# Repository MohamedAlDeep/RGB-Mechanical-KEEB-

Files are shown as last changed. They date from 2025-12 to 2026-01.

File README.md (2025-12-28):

# RGB Mechanical 75% KEEB

This is my custom made 75% rgb mechanical keyboard, it has per-key lights and hot swapable key switches.

> Why I made this project:

Because i have a laptop and i haven't had any actual separate keyboard experience, so i wanted to have one, and thought it would be nice for me to make my own for flexing on my fellows and solidify my PCB desiging knowledge.

--------------------------------

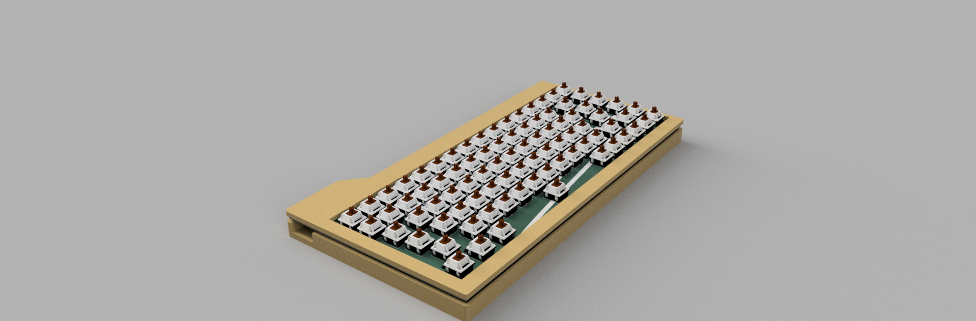
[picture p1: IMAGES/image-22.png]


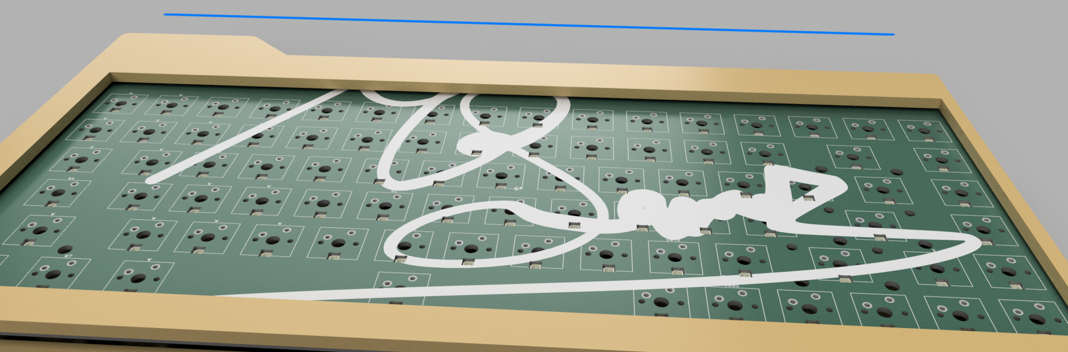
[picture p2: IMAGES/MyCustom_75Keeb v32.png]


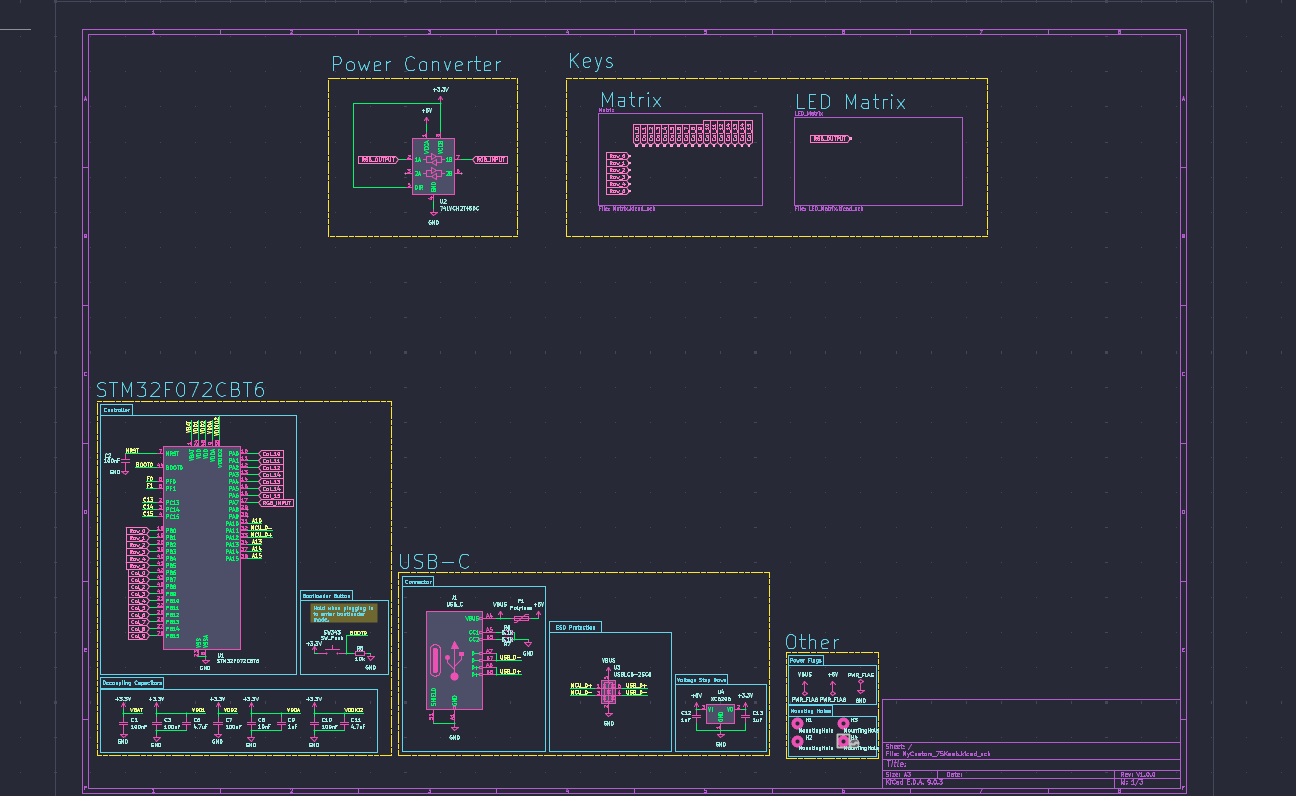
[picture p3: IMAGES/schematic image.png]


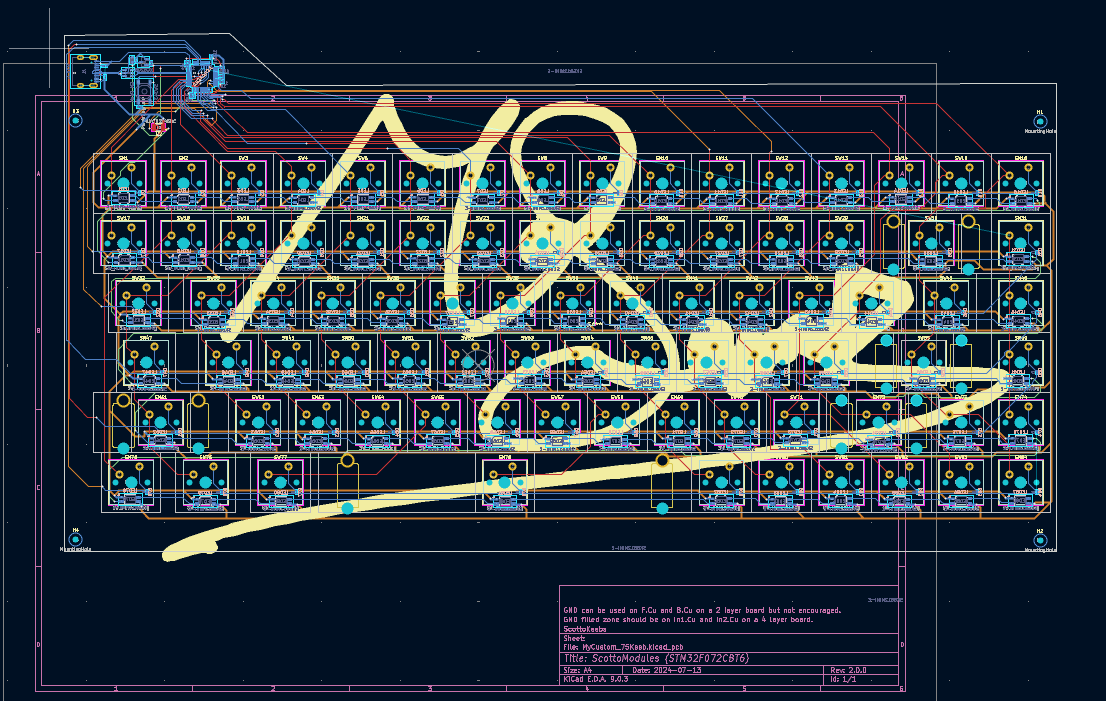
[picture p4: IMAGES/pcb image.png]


## BOM

| Id | Designator | Footprint PCB ONLY | Quantity | Designation | Supplier (LINK) | Price | Total |
|:---|:---|:---|:---|:---|:---|:---|:---|
| | New 104 Pcs Mechanical Keyboard Keycaps Set OEM Replacement Backlit ABS Purple White Key Cap for 61/87/104 Key Cherry MX Keycap | | 1.0 | | [Link](https://ar.aliexpress.com/item/1005005259313543.html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) | 8.06 | 8.06 |
| 6 | GATERON G Pro 3.0 Switches Pre-lubed 5 pinS RGB Linear for Gaming Mechanical Keyboard (Yellow) | | 1.0 | | [Link](https://ar.aliexpress.com/item/1005005862014771.html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) | 10.69 | 10.69 |
| 7 | U2 | VSSOP-8_2.3x2mm_P0.5mm | 1.0 | 74LVCH2T45DC | [Link](https://jlcpcb.com/partdetail/Nexperia-74LVCH2T45DC125/C548924) | 0.564 | 0.564 |
| 8 | LED81,LED30,LED64,LED1,LED58,LED17,LED39,LED36,LED47,LED24,LED80,LED20,LED31,LED68,LED23,LED7,LED63,LED2,LED70,LED26,LED73,LED5,LED67,LED3,LED85,LED25,LED62,LED18,LED69,LED41,LED13,LED9,LED46,LED48,LED53,LED86,LED38,LED42,LED44,LED14,LED71,LED83,LED11,LED12,LED15,LED76,LED72,LED84,LED32,LED29,LED37,LED51,LED59,LED79,LED28,LED56,LED8,LED19,LED65,LED35,LED57,LED10,LED60,LED43,LED34,LED61,LED27,LED16,LED87,LED50,LED45,LED54,LED40,LED22,LED4,LED6,LED82,LED74,LED78,LED21,LED49,LED75,LED33,LED52 | LED_6028R | 84.0 | SK6812MINI-E | [Link](https://jlcpcb.com/partdetail/OPSCOOptoelectronics-SK6812MINIE/C5149201) | 0.0578 | 4.8552 |
| 9 | D77,D49,D82,D24,D37,D76,D83,D3,D81,D58,D72,D56,D40,D10,D45,D53,D20,D16,D28,D70,D1,D52,D38,D19,D11,D41,D50,D34,D9,D64,D22,D23,D47,D12,D43,D80,D2,D14,D17,D67,D7,D5,D71,D42,D78,D73,D68,D57,D33,D4,D65,D69,D13,D66,D27,D36,D74,D32,D15,D6,D84,D31,D8,D18,D61,D39,D46,D48,D30,D55,D35,D62,D60,D51,D59,D29,D25,D63,D21,D26,D44,D79,D75,D54 | D_0201_0603Metric | 84.0 | D | [Link](https://jlcpcb.com/partdetail/Comchip-CZRU52C2V7HF/C2886070) | 0.06 | 5.04 |
| 10 | R7,R6 | Resistor_0402 | 2.0 | 5.1k | [Link](https://jlcpcb.com/partdetail/26487-0402WGF1002TCE/C25744) | 0.0006 | 0.0012 |
| 11 | C10,C7,C3,C1,C2 | Capacitor_0402 | 5.0 | 100nF | [Link](https://jlcpcb.com/partdetail/1877-CL05B104KO5NNNC/C1525) | 0.0012 | 0.006 |
| 12 | J1 | USB_C_HRO_TYPE-C-31-M-12 | 1.0 | USB_C | [Link](https://jlcpcb.com/partdetail/Korean_HropartsElec-TYPE_C_31_M12/C165948) | 0.17 | 0.17 |
| 13 | U3 | ESD_SOT-23-6 | 1.0 | USBLC6-2SC6 | [Link](https://jlcpcb.com/partdetail/2790619-USBLC62SC6/C2687116) | 0.0368 | 0.0368 |
| 14 | C8 | Capacitor_0402 | 1.0 | 10nF | [Link](https://jlcpcb.com/partdetail/53938-CL05A105KA5NQNC/C52923) | 0.0029 | 0.0029 |
| 15 | U1 | Package_LQFP-48_7x7mm_P0.5 | 1.0 | STM32F072CBT6 | [Link](https://jlcpcb.com/partdetail/STMicroelectronics-STM32F072CBT6/C81720) | 1.3005 | 1.3005 |
| 16 | C12,C9,C13 | Capacitor_0402 | 3.0 | 1uF | [Link](https://jlcpcb.com/partdetail/15869-CL05B103KB5NNNC/C15195) | 0.0014 | 0.0042 |
| 17 | C11,C6 | Capacitor_0402 | 2.0 | 4.7uF | [Link](https://jlcpcb.com/partdetail/24469-CL05A475MP5NRNC/C23733) | 0.0046 | 0.0092 |
| 18 | U4 | Voltage_SOT-23 | 1.0 | XC6206 | [Link](https://jlcpcb.com/partdetail/TorexSemicon-XC6206P332MRG/C5446) | 0.0998 | 0.0998 |
| 19 | R5 | Resistor_0402 | 1.0 | 10k | [Link](https://jlcpcb.com/partdetail/26648-0402WGF5101TCE/C25905) | 0.0005 | 0.0005 |
| 20 | F1 | Fuse_0603 | 1.0 | 500mA | [Link](https://jlcpcb.com/partdetail/Hongda-2009T500mA250V/C529783) | 0.0551 | 0.0551 |
| 21 | SW343 | Button_TL3342 | 1.0 | SW_Push | [Link](https://jlcpcb.com/partdetail/Alpsalpine-SKQGABE010/C115351) | 0.0005 | 0.0005 |
| TOTAL IN USD | | | | | | | 31.5458 |

Add 15 usd for shipping and tax

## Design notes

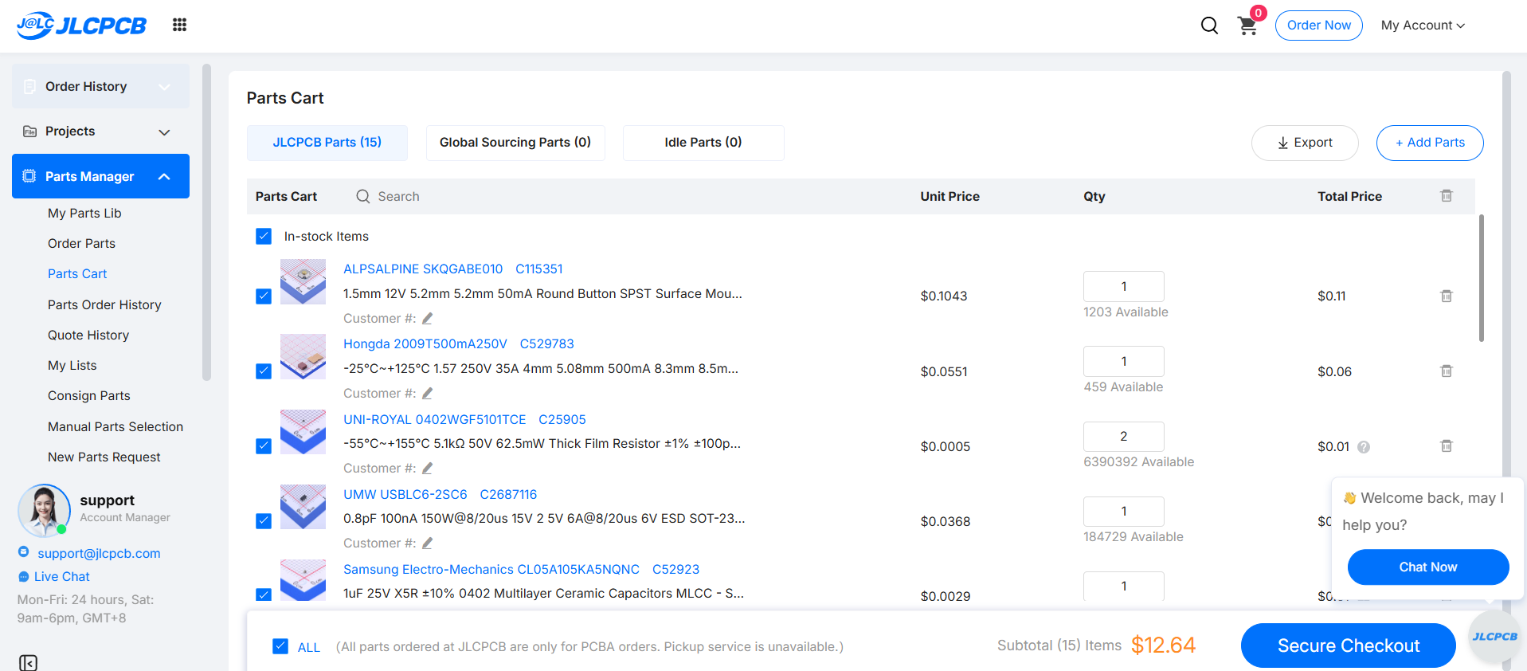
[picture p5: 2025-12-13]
IMAGES/JLCPCB_CART.png

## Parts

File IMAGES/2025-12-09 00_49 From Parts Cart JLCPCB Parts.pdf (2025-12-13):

## Parts Type

## JLCPCB

Part # | MFR Part #
stock | C115351 | SKQGABE010
stock | C529783 | 2009T500mA250V
stock | C25905 | 0402WGF5101TCE
stock | C2687116 | USBLC6-2SC6
stock | C52923 | CL05A105KA5NQNC
stock | C81720 | STM32F072CBT6
stock | C15195 | CL05B103KB5NNNC
stock | C23733 | CL05A475MP5NRNC
stock | C5446 | XC6206P332MR-G
stock | C548924 | 74LVCH2T45DC,125
stock | C5149201 | SK6812MINI-E
stock | C2886070 | CZRU52C2V7-HF
stock | C25744 | 0402WGF1002TCE
stock | C1525 | CL05B104KO5NNNC
stock | C165948 | TYPE-C-31-M-12

TOTAL

## Description

1.5mm 12V 5.2mm 5.2mm 50mA Round Button SPST Surface Mount,Vertical SMD-4P,5.2x5.2mm Tactile Switches ROHS -25℃~+125℃ 1.57 250V 35A 4mm 5.08mm 500mA 8.3mm 8.5mm Square Fuse Plugin,P=5.08mm Disposable fuses ROHS -55℃~+155℃ 5.1kΩ 50V 62.5mW Thick Film Resistor ±1% ±100ppm/℃ 0402 Chip Resistor - Surface Mount ROHS 0.8pF 100nA 150W@8/20us 15V 2 5V 6A@8/20us 6V ESD SOT-23-6 ESD and Surge Protection (TVS/ESD) ROHS 1uF 25V X5R ±10% 0402 Multilayer Ceramic Capacitors MLCC - SMD/SMT ROHS 1.65V~3.6V 128KB 12bit 12bit 37 48MHz ARM-M0 FLASH LQFP-48(7x7) Microcontrollers (MCU/MPU/SOC) ROHS 10nF 50V X7R ±10% 0402 Multilayer Ceramic Capacitors MLCC - SMD/SMT ROHS 10V 4.7uF X5R ±20% 0402 Multilayer Ceramic Capacitors MLCC - SMD/SMT ROHS -40℃~+85℃@(Ta) 1 1uA 200mA 3.3V 6V Fixed Over Current Protection Positive SOT-23-3L Voltage Regulators - Linear, Low Drop Out (LDO) Regulators ROHS -40℃~+125℃ 1 1.2V~5.5V 1.2V~5.5V 2 420Mbps Bidirectional Power-Off Protection Tri-State VSSOP-8-0.5mm Translators, Level Shifters ROHS -40℃~+85℃ 0.6mA 1.78mm 120° 1kHz 2.8mm 2000V 3.2mm 3.7V~5.5V 800Kbit/s G:815mcd~1275mcd R:620nm~625nm Semi-transparent lens SMD RGB LEDs(Built-in IC) ROHS -55℃~+125℃ 150mW 2.57V~2.84V 2.7V 500Ω 75uA@1V 83Ω Independent 0603(SOD-523F) Zener Diodes ROHS -55℃~+155℃ 10kΩ 50V 62.5mW Thick Film Resistor ±1% ±100ppm/℃ 0402 Chip Resistor - Surface Mount ROHS 100nF 16V X7R ±10% 0402 Multilayer Ceramic Capacitors MLCC - SMD/SMT ROHS 1 16P 5A Female Type-C SMD USB Connectors ROHS

## Unit Price

Q
t
y

## Total Price

0.1043 | 1 | 0.11
0.0551 | 1 | 0.06
0.0005 | 2 | 0.01
0.0368 | 1 | 0.04
0.0029 | 1 | 0.01
1.3005 | 1 | 1.31
0.0014 | 3 | 0.01
0.0046 | 2 | 0.01
0.0998 | 1 | 0.1
0.564 | 1 | 0.57
0.066 | 84 | 5.55
0.0555 | 84 | 4.67
0.0005 | 2 | 0.01
0.0012 | 5 | 0.01
0.1694 | 1 | 0.17

12.64

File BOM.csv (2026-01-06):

Id | Designator | Footprint PCB ONLY | Quantity | Designation | Supplier (LINK) | Price | Total
1 | New 104 Pcs Mechanical Keyboard Keycaps Set OEM Replacement Backlit ABS Purple White Key Cap for 61/87/104 Key Cherry MX Keycap |  | 1 |  | https://ar.aliexpress.com/item/1005005259313543.html?curPageLogUid=Hf3LitEjKJwR | 8.06 | 8.06
2 | GATERON G Pro 3.0 Switches Pre-lubed 5 pinS RGB Linear for Gaming Mechanical Keyboard (Yellow) |  | 1 |  | https://ar.aliexpress.com/item/1005005862014771.html?curPageLogUid=BugaJfZUgWLk | 10.69 | 10.69
3 | U2 | VSSOP-8_2.3x2mm_P0.5mm | 1 | 74LVCH2T45DC | https://jlcpcb.com/partdetail/Nexperia-74LVCH2T45DC125/C548924 | 0.564 | 0.564
4 | LED81,LED30,LED64,LED1,LED58,LED17,LED39,LED36,LED47,LED24,LED80,LED20,LED31,LED68,LED23,LED7,LED63,LED2,LED70,LED26,LED73,LED5,LED67,LED3,LED85,LED25,LED62,LED18,LED69,LED41,LED13,LED9,LED46,LED48,LED53,LED86,LED38,LED42,LED44,LED14,LED71,LED83,LED11,LED12,LED15,LED76,LED72,LED84,LED32,LED29,LED37,LED51,LED59,LED79,LED28,LED56,LED8,LED19,LED65,LED35,LED57,LED10,LED60,LED43,LED34,LED61,LED27,LED16,LED87,LED50,LED45,LED54,LED40,LED22,LED4,LED6,LED82,LED74,LED78,LED21,LED49,LED75,LED33,LED52 | LED_6028R | 84 | SK6812MINI-E | https://jlcpcb.com/partdetail/OPSCOOptoelectronics-SK6812MINIE/C5149201 | 0.0578 | 4.8552
5 | D77,D49,D82,D24,D37,D76,D83,D3,D81,D58,D72,D56,D40,D10,D45,D53,D20,D16,D28,D70,D1,D52,D38,D19,D11,D41,D50,D34,D9,D64,D22,D23,D47,D12,D43,D80,D2,D14,D17,D67,D7,D5,D71,D42,D78,D73,D68,D57,D33,D4,D65,D69,D13,D66,D27,D36,D74,D32,D15,D6,D84,D31,D8,D18,D61,D39,D46,D48,D30,D55,D35,D62,D60,D51,D59,D29,D25,D63,D21,D26,D44,D79,D75,D54 | D_0201_0603Metric | 84 | D | https://jlcpcb.com/partdetail/Comchip-CZRU52C2V7HF/C2886070 | 0.06 | 5.04
6 | R7,R6 | Resistor_0402 | 2 | 5.1k | https://jlcpcb.com/partdetail/26487-0402WGF1002TCE/C25744 | 0.0006 | 0.0012
7 | C10,C7,C3,C1,C2 | Capacitor_0402 | 5 | 100nF | https://jlcpcb.com/partdetail/1877-CL05B104KO5NNNC/C1525 | 0.0012 | 0.006
8 | J1 | USB_C_HRO_TYPE-C-31-M-12 | 1 | USB_C | https://jlcpcb.com/partdetail/Korean_HropartsElec-TYPE_C_31_M12/C165948 | 0.17 | 0.17
9 | U3 | ESD_SOT-23-6 | 1 | USBLC6-2SC6 | https://jlcpcb.com/partdetail/2790619-USBLC62SC6/C2687116 | 0.0368 | 0.0368
10 | C8 | Capacitor_0402 | 1 | 10nF | https://jlcpcb.com/partdetail/53938-CL05A105KA5NQNC/C52923 | 0.0029 | 0.0029
11 | U1 | Package_LQFP-48_7x7mm_P0.5 | 1 | STM32F072CBT6 | https://jlcpcb.com/partdetail/STMicroelectronics-STM32F072CBT6/C81720 | 1.3005 | 1.3005
12 | C12,C9,C13 | Capacitor_0402 | 3 | 1uF | https://jlcpcb.com/partdetail/15869-CL05B103KB5NNNC/C15195 | 0.0014 | 0.0042
13 | C11,C6 | Capacitor_0402 | 2 | 4.7uF | https://jlcpcb.com/partdetail/24469-CL05A475MP5NRNC/C23733 | 0.0046 | 0.0092
14 | U4 | Voltage_SOT-23 | 1 | XC6206 | https://jlcpcb.com/partdetail/TorexSemicon-XC6206P332MRG/C5446 | 0.0998 | 0.0998
15 | R5 | Resistor_0402 | 1 | 10k | https://jlcpcb.com/partdetail/26648-0402WGF5101TCE/C25905 | 0.0005 | 0.0005
16 | F1 | Fuse_0603 | 1 | 500mA | https://jlcpcb.com/partdetail/Hongda-2009T500mA250V/C529783 | 0.0551 | 0.0551
17 | SW343 | Button_TL3342 | 1 | SW_Push | https://jlcpcb.com/partdetail/Alpsalpine-SKQGABE010/C115351 | 0.0005 | 0.0005
Components JLC cart (1x Comonents) |  |  |  |  |  |  | 30.8959
PCB 5 pics (JLCPCB) |  |  |  |  |  |  | 50
Total |  |  |  |  |  |  | 80.8959

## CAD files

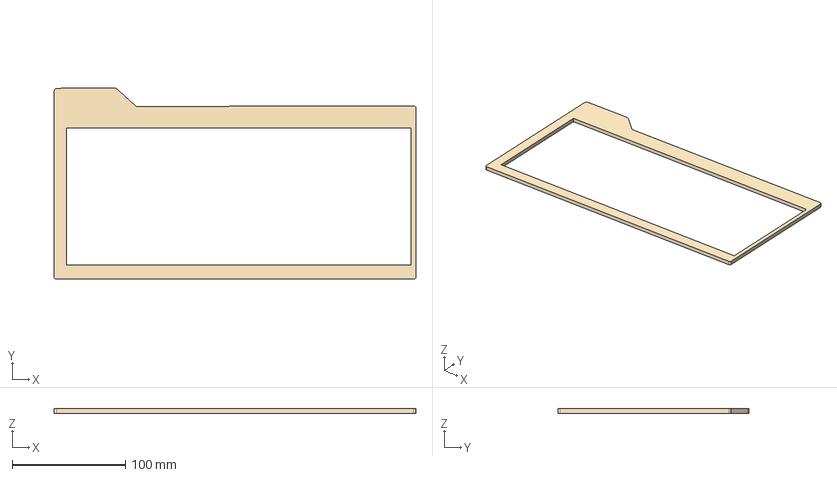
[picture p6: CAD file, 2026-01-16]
CAD/PCB_Case_UPPER.step
319.6 x 168.9 x 4.00 mm

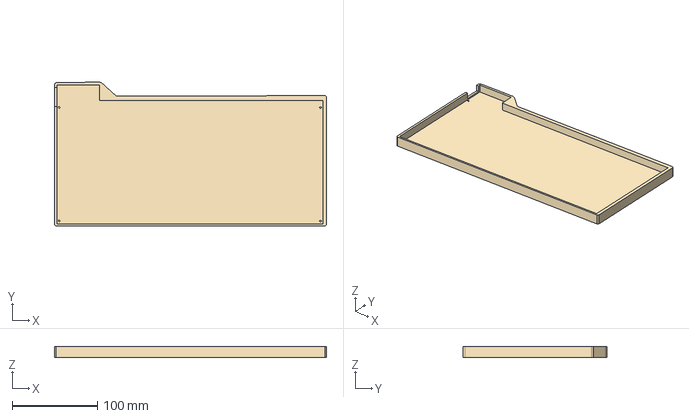
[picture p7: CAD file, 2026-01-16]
CAD/PCB_CASE_BOTTOM.step
319.6 x 168.9 x 13.0 mm

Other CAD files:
CAD/MyCustom_75Keeb_UpperModule.stl
CAD/MyCustom_75Keeb_BottomModule.stl

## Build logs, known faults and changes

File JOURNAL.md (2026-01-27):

# JOURNAL
> Total time: 16.6h

## Building an Idea
> Time spent 0.5h

> 23/11/2025 

I open keyboard layout editor to start choosing a layout, i chose the one in the image below and i also want to have a rotary encoder.

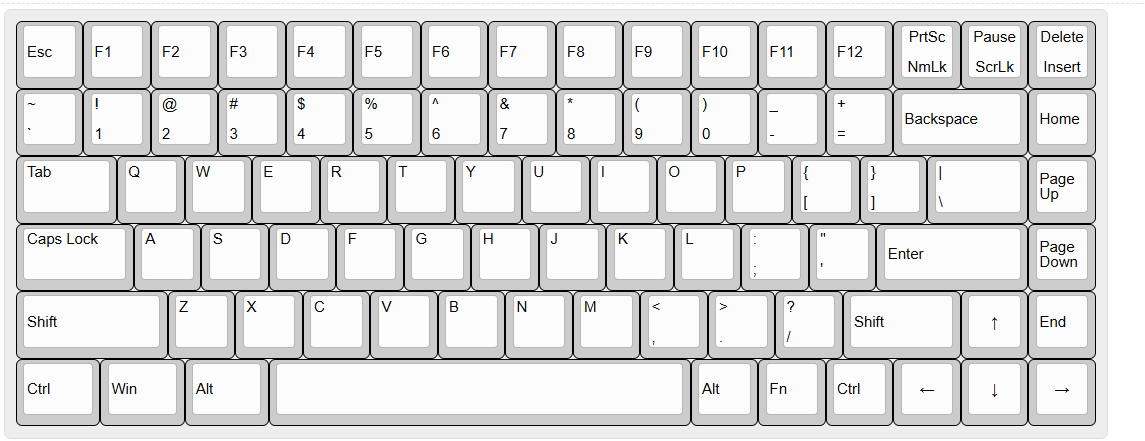
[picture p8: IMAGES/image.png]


As shown it is a 75% keyboard, i am planning to have a rotary encoder maybe multiple ones.

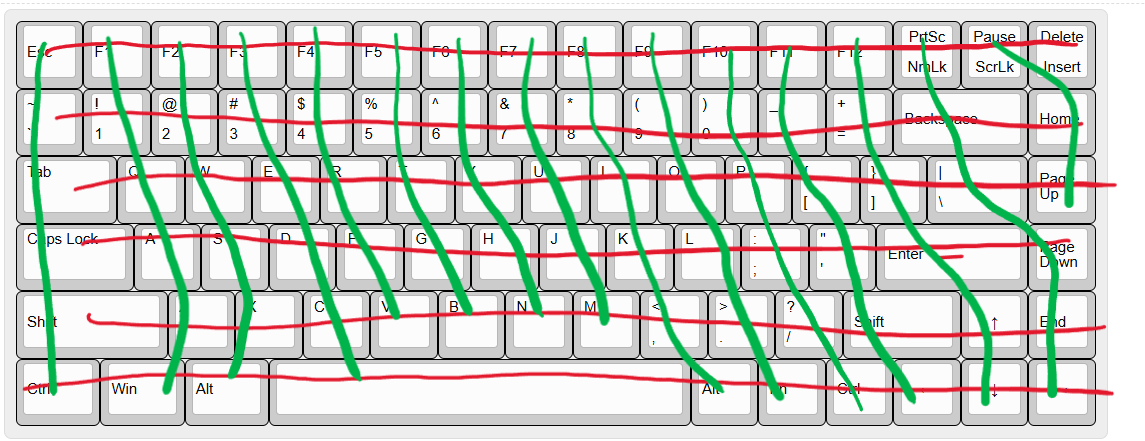
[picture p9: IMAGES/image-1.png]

---------------------------------------------
## First hands on Schematic
> 25/11/2025
## MCU
### Controller Chip
For the chip i chose a common chip which is the STM32F072CBT6 is has many GPIOs, i am not sure if it would take everything i need but until now it should work.

I have started giving out labels to the pins just regular names and connected ground pins to ground

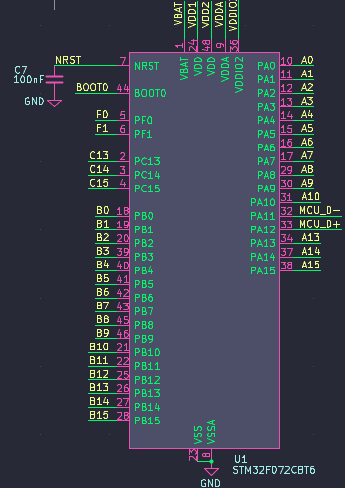
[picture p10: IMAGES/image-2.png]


### Decoupling Caps
In decoupling capacitors area i followed the general guides and made very standard connections.



### Boot button
Made a bootloader button circuit.

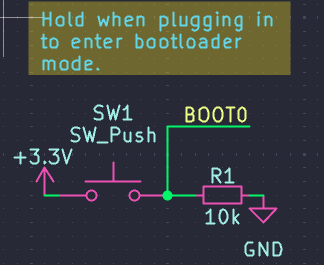
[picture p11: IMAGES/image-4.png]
 

## Power Supply
### USB-C port
Here i am connecting ground then the data differentials and following standard connection for CC1 and CC2 by pulling them to ground and for vbus i am connecting fuse for current limit

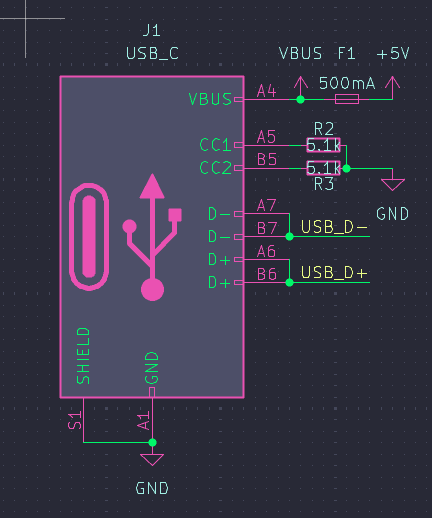
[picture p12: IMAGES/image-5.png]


### Static Elect.. Protection
ESD protection circuit, connected from the USB then to the chip for static electricity protection.

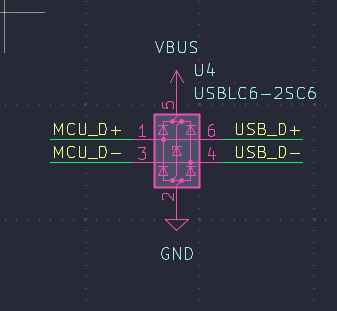
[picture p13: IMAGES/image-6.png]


### Voltage stepdown
Finally i made voltage stepdown from USB to 3.3v.

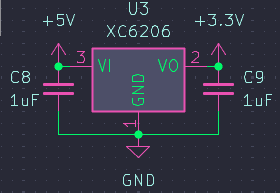
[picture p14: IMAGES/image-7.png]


### Misc
At the end i added mounting holes for the keyboard, i stick with 4 holes as i think the keyboard is compact enough for those.



-------------------------------------
## Keyboard Keys Schematic
> 26/11/2025    
### Keys
To start making the key matrix i open a new sheet and i started putting down the 45 angled switch key and the diode, then i copied the same thing for the total number of keys, then i connected the matrix for columns and rows and added the global labels, to finish with the exact number of keys i removed additional ones in the matrix leaving space for shift and spacebar and other keys making the schematic ready to pull into the pcb editor.

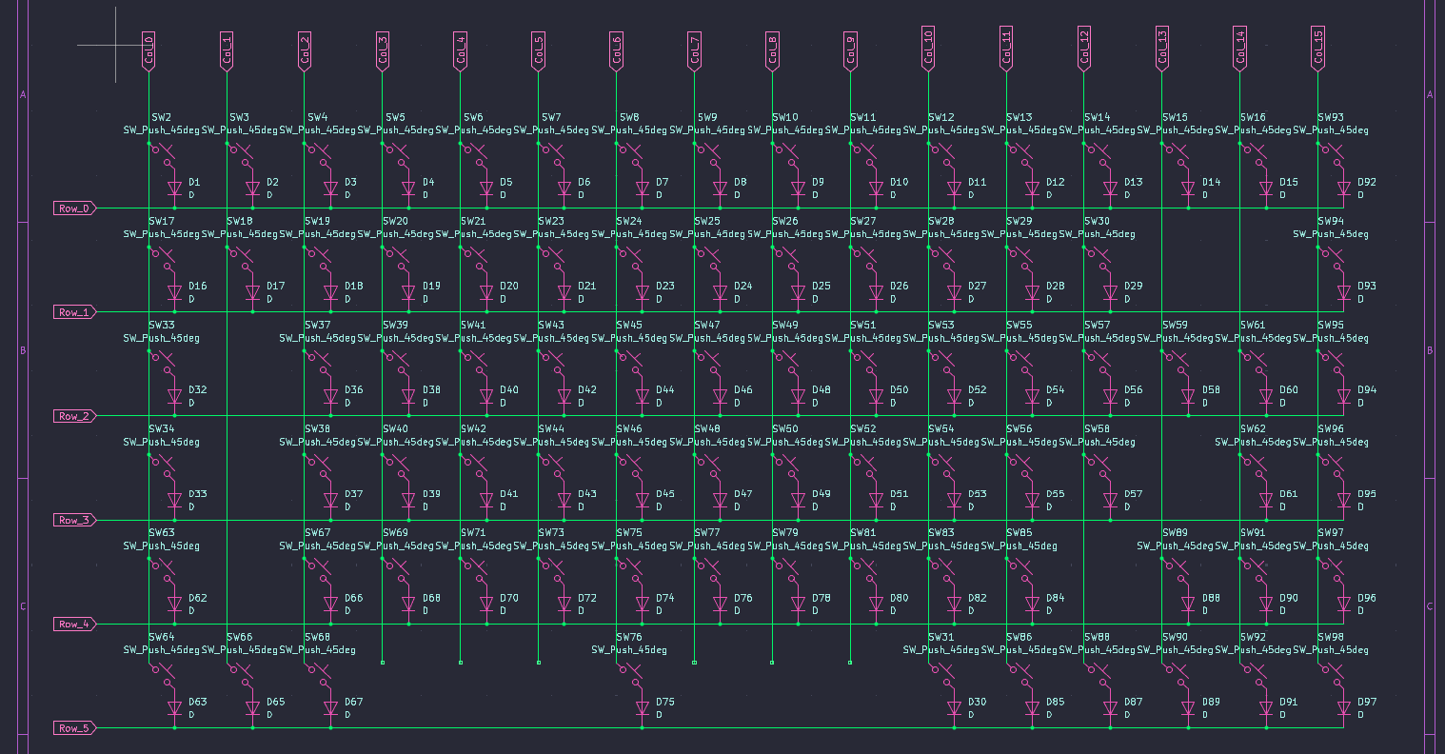
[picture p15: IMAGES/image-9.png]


Here is the final result in the main schematic sheet with the global labels

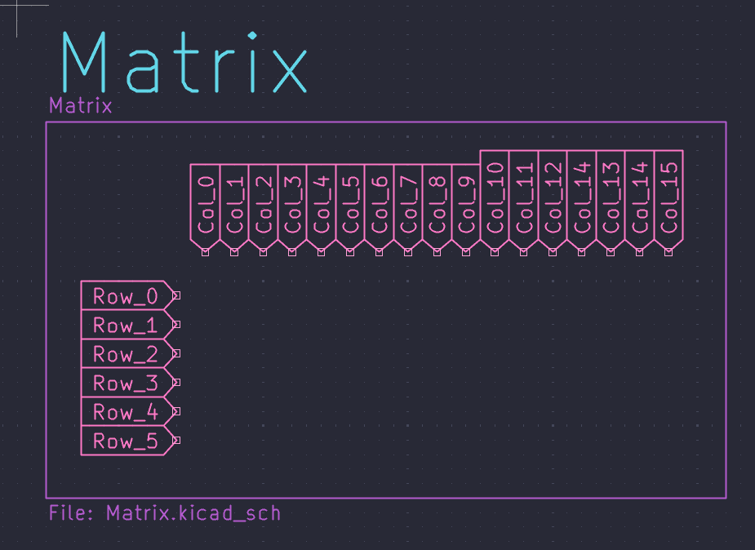
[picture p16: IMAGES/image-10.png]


### LEDs
For the addressable RGB leds i use the SK6812, i got the 84 leds for each key on the layout, with that i started connecting them in series, and gave global label for the converted power coming from the MCU.

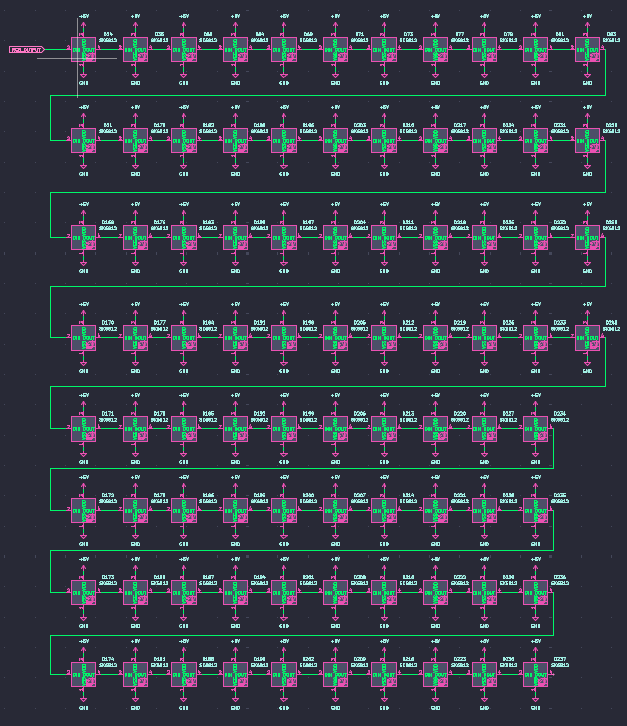
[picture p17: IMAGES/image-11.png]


### LED Power Converter
In order to have stable signal coming from the MCU and flowing to the final led without degradation of signal i convert the 3.3v to 5v for the Signal lines, using the 74LVCH2T45DC and connecting in as the following.

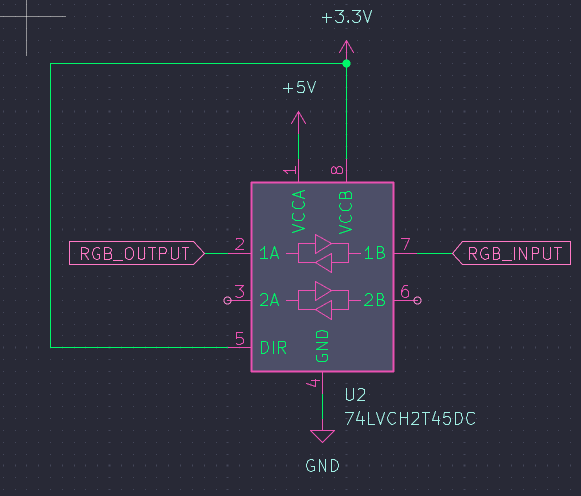
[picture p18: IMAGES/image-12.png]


### Rotary Encoder
I have added this rotary encoder gave it a traditional connection i found on a tutorial, i am going to change the labels for the matrix.

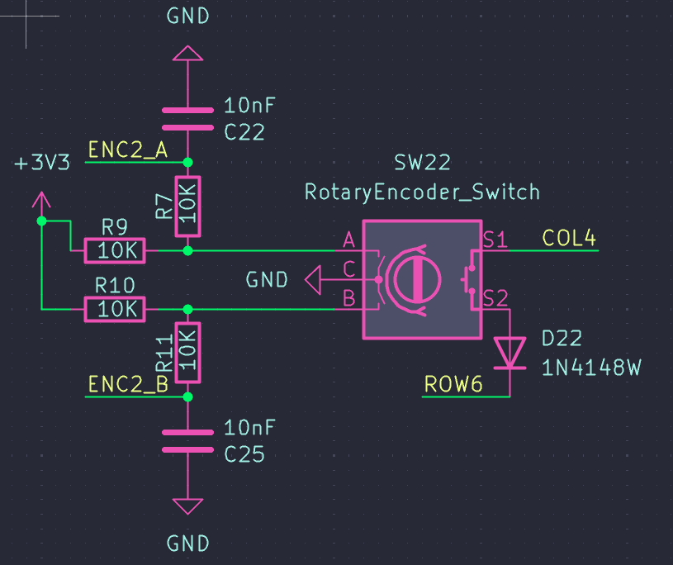
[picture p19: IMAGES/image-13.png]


### Schematic Polishing
Making titles and box areas for each part.

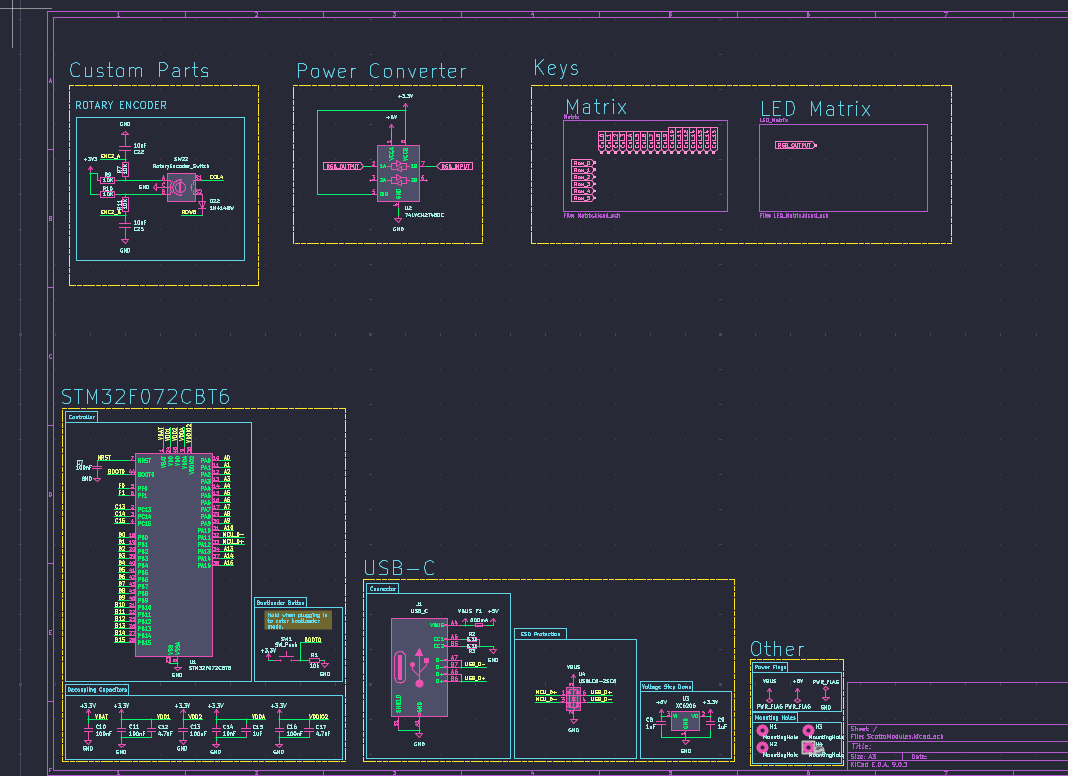
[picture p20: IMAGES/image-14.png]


----------------------------------------------
## PCB & Layout
> 28/11/2025
### Schematic addition
I have added additional parts in schematic which are the stabilizers.

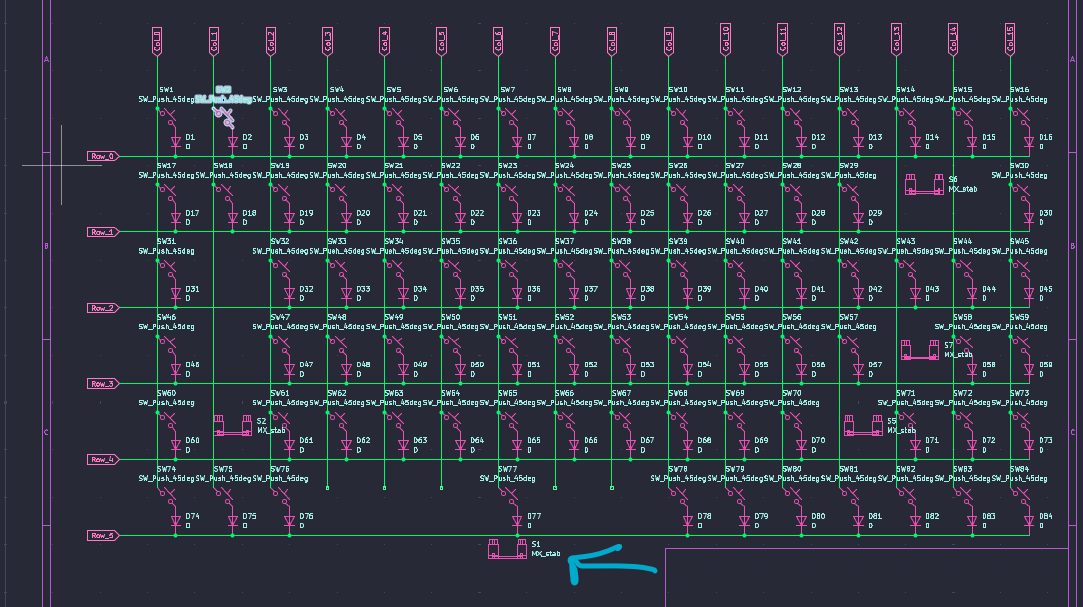
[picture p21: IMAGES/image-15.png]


I have changed the leds footprint to the SK mini which are much smaller in size from the main mini.

### PCB Auto Layout
I pulled all components then used the kbplacer plugin for layout, it auto connected some of the columns and rows so i had few left unconnected to connect then i placed the stabalizers according to their sizes.

This process took some time as i had multiple issues when auto placing LEDs using the plugin, for some reason the plugin was not capable of doing it so i had to remove the leds then pull them back after auto placement.

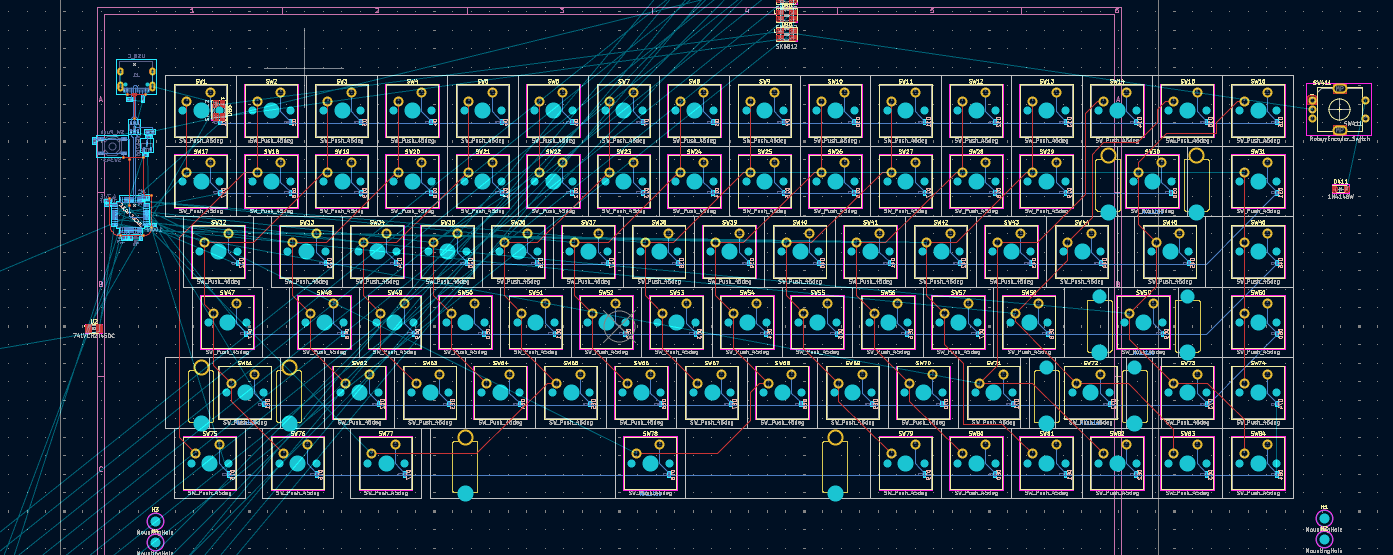
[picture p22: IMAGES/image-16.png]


### MCU
The microcontroller was connected to the USB-C from a preloaded template.

----------------------------------------------

## LEDs
> 4/12/2025 

This was the most tiring phase because i realized i was using the wrong led footprint so i had to change the schematic symbol and added the SK mini e reverse mount version of led so i can put it anywhere as it doesn't interfere with the upper layer.

Then i had to place every led in its place below the 3 pin holes and then i started connecting each single power pin to a main +5v power line and repeat that every single led, then i made the same changes again for the ground pins and then try to figure out how to connect the other two (DIN-DOUT) signal pins
so i worked on the inner layers of the board and connect every SINGLE LED which was absolute pain, but at the end i got it all together.

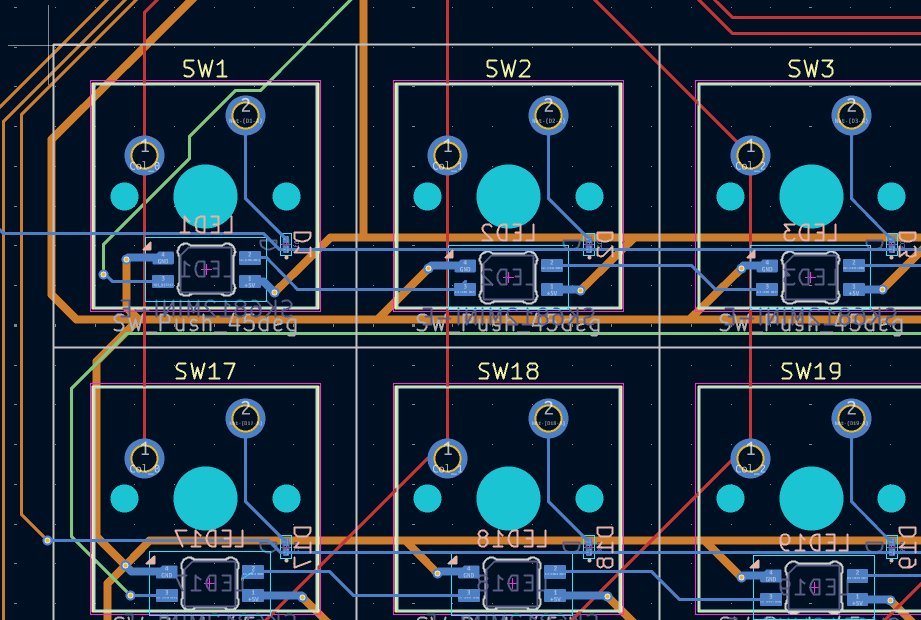
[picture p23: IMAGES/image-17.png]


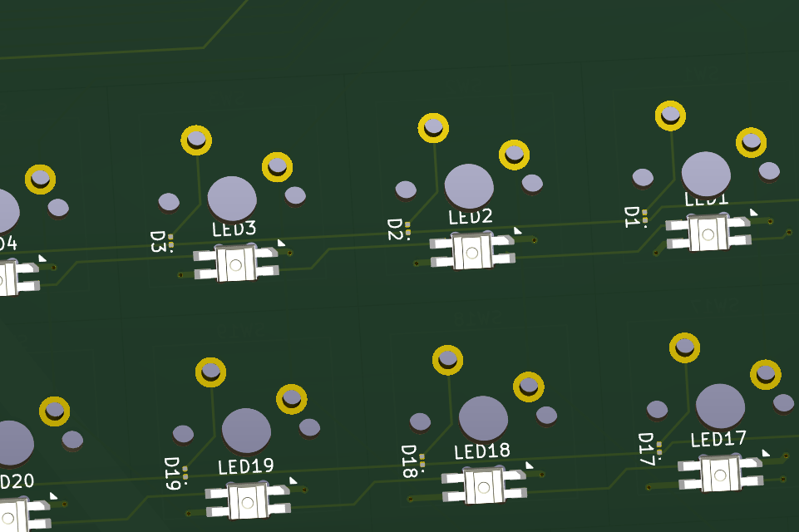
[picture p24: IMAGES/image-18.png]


--------------------------------------------
## MCU Connections
> 4/12/2025

I think the image speaks for itself, yes i had to do that and do cross overs which was crazy as somehow the pins where not in correct order for the matrix cols and rows so had to put a lot of vias in order to get it done.

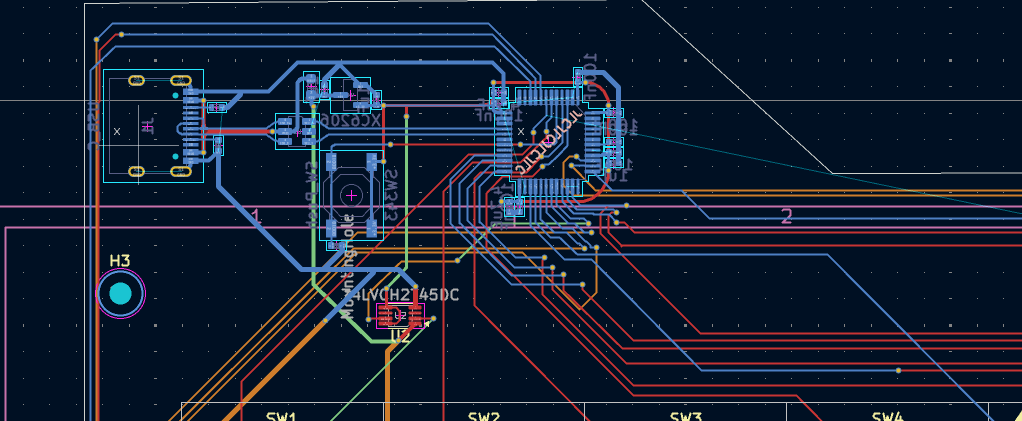
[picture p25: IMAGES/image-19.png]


---------------------------------------------
## Keyboard Case
This was easy task i am good in CAD so i made a simple flat case no fancy things i made it in Fusion360 and got it done then i rendered the images with the exported PCB, The case is simply an external outline of the pcb with a side opening for the usb-c port.



The keyboard case is made of one large outer rectangle that is filled and holds the general pcb.

The small rectangle extension holds the place where the pcb has the MCU.

The outer line gives nice shape to the pcb.

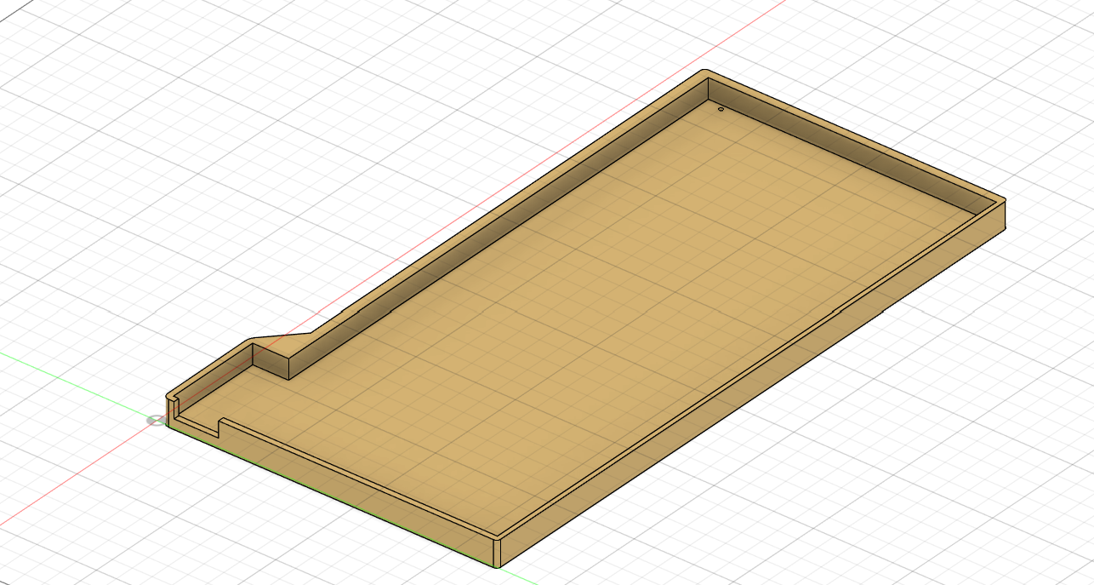
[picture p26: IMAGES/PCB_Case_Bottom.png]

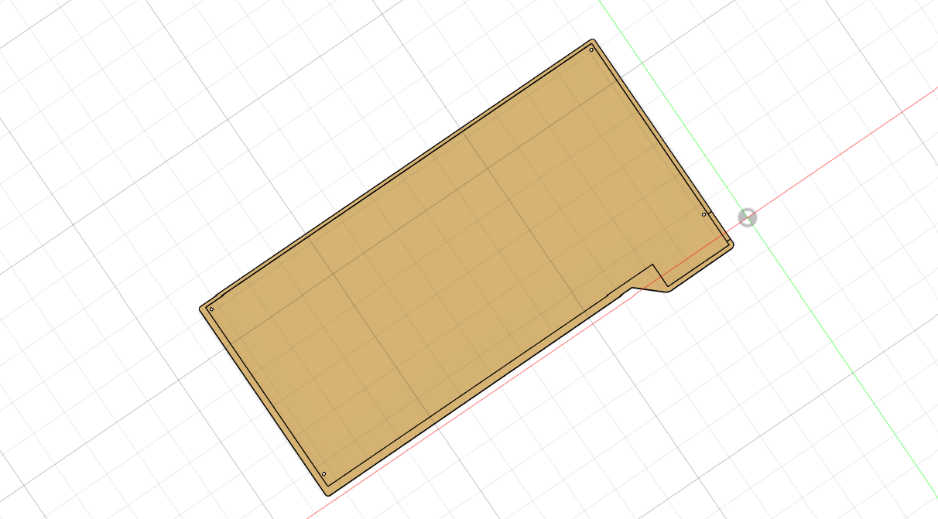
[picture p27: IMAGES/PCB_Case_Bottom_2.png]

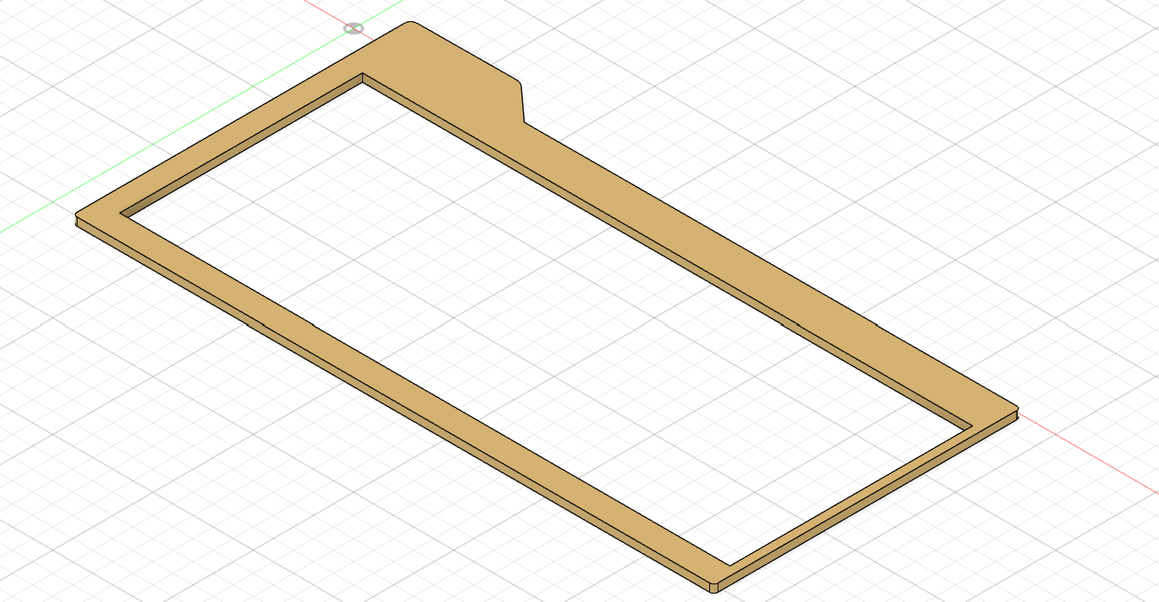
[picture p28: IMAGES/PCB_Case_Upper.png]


### End Result
> 4/12/2025
At the end i added my signiture on the front silkscreen and exported the pcb.

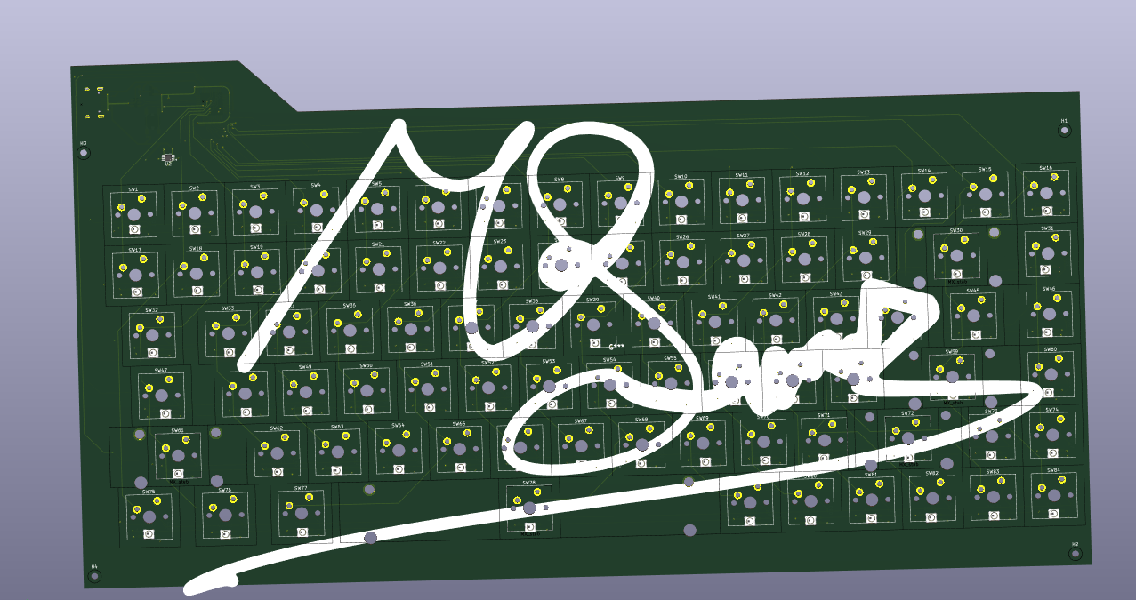
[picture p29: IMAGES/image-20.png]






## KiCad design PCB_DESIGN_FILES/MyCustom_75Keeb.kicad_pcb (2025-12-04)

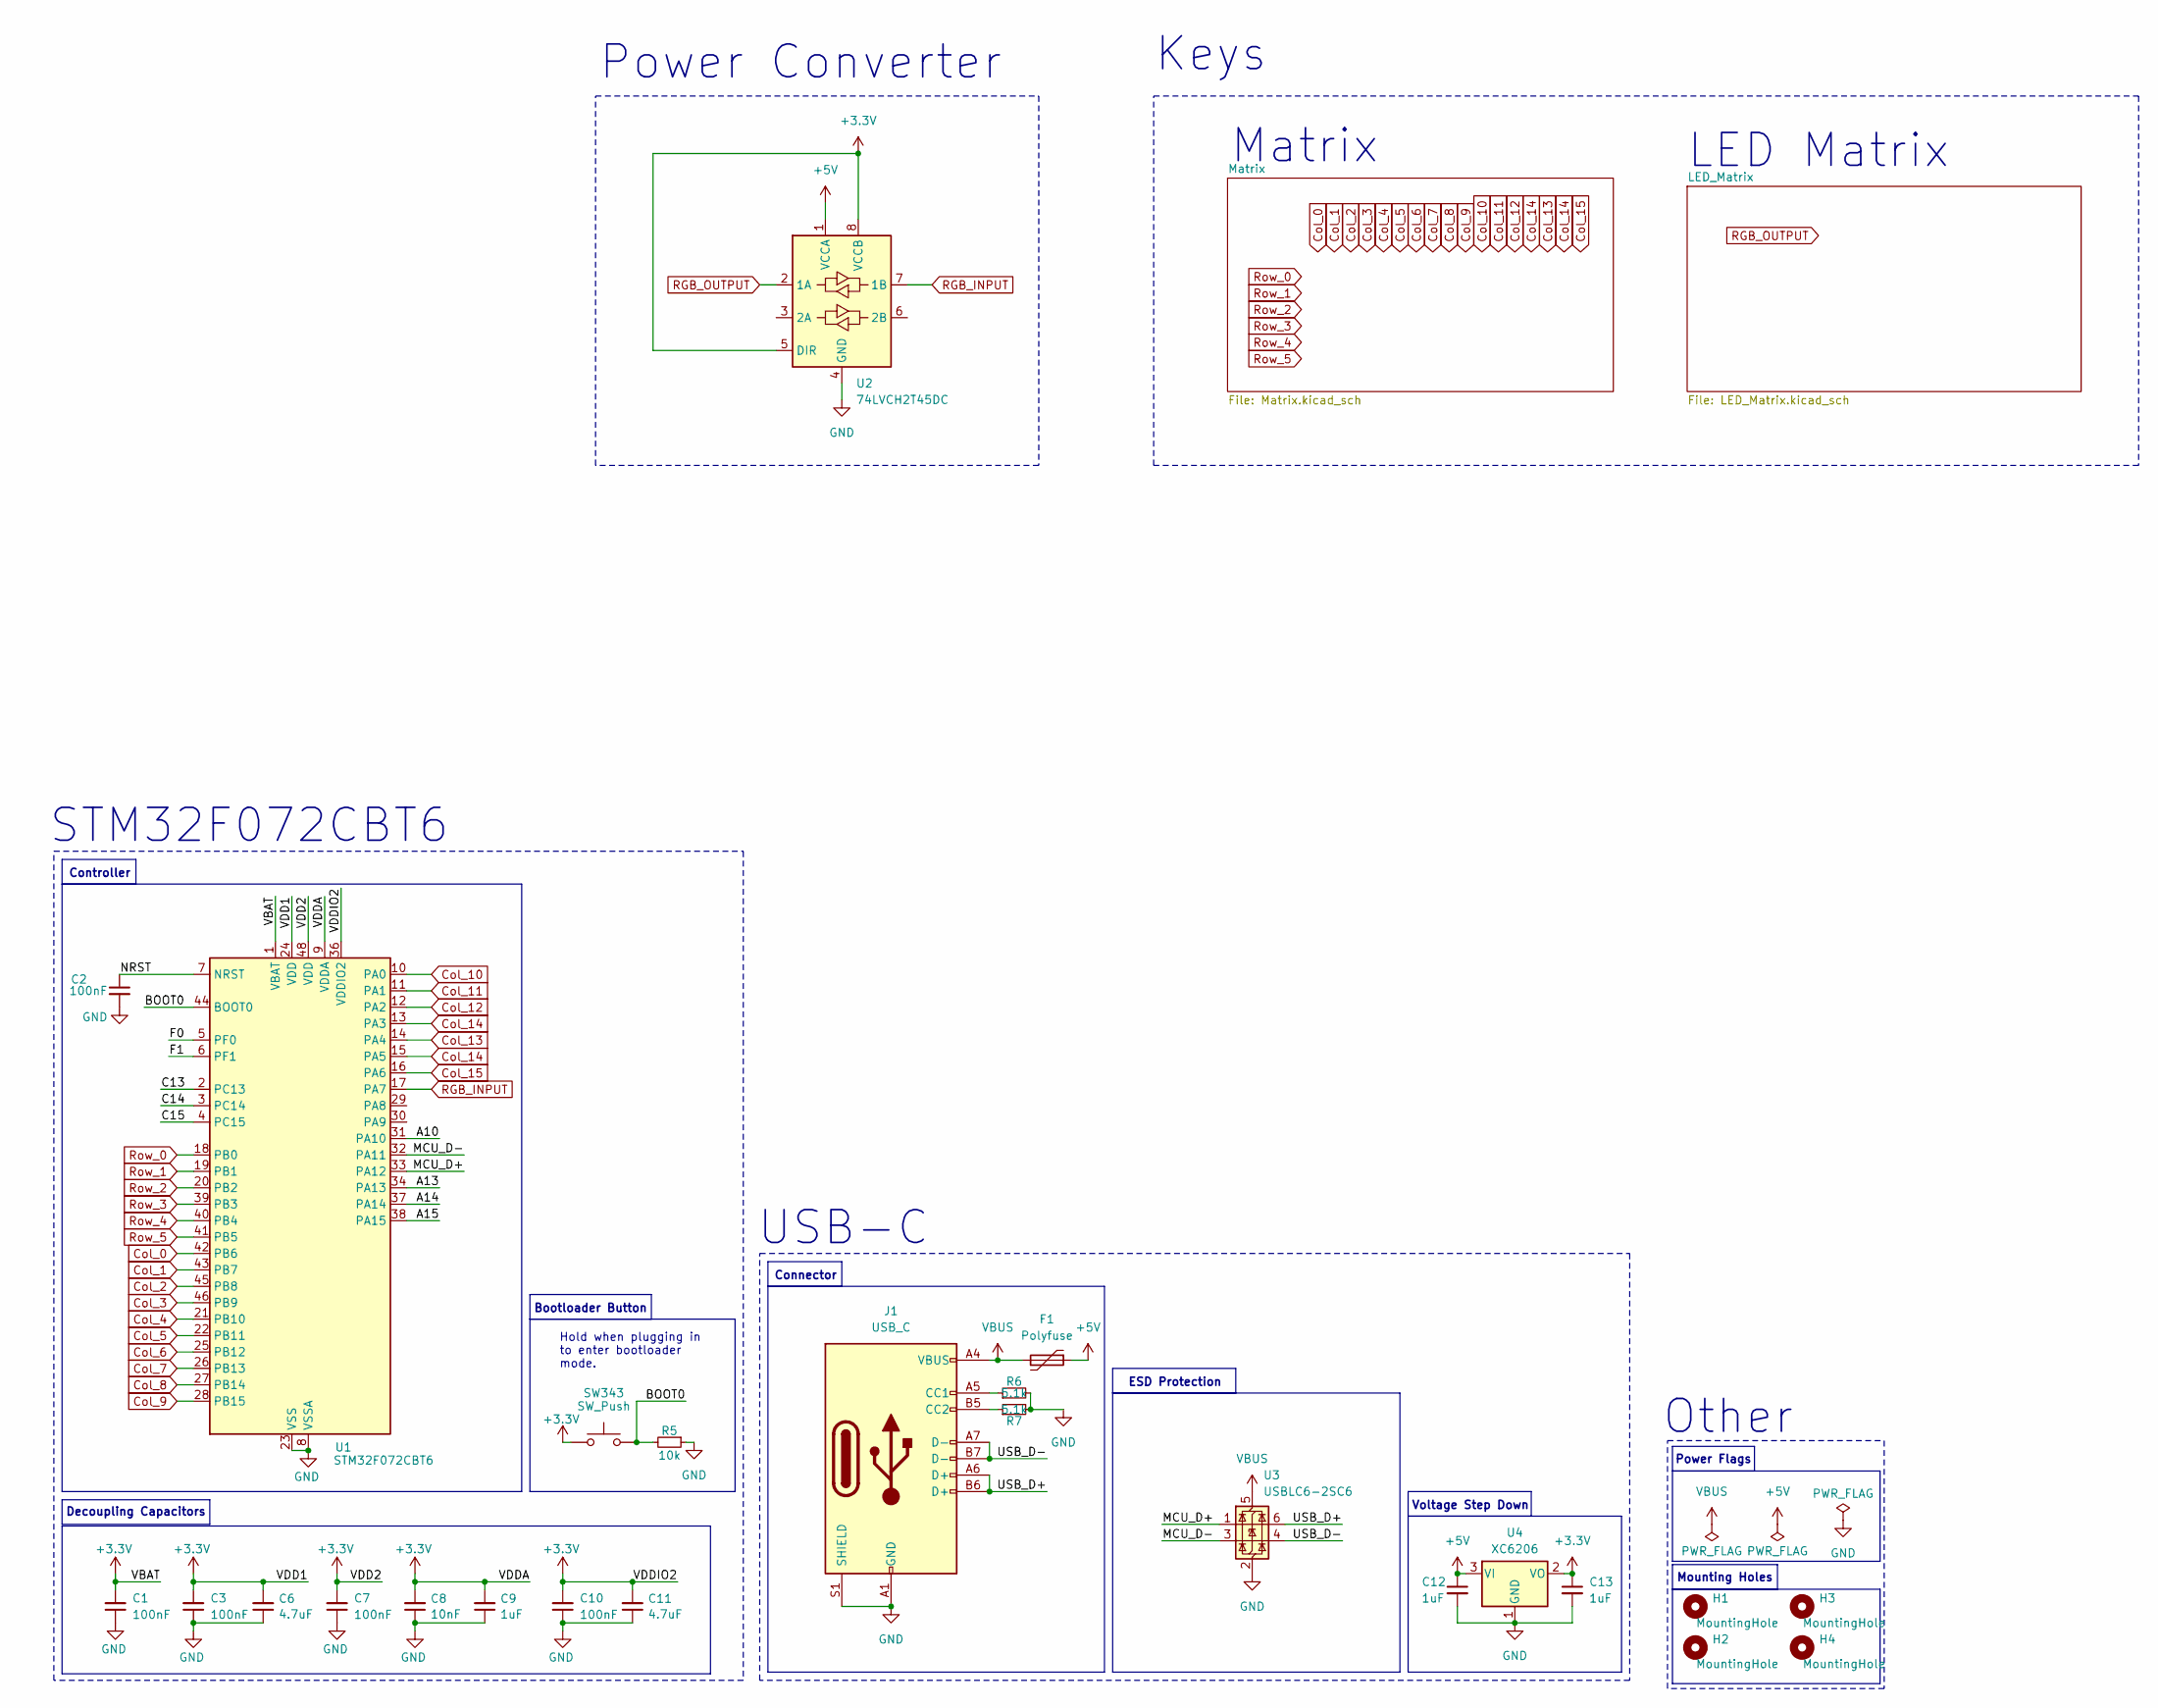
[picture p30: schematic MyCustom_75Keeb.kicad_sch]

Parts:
C1, C3, C7, C10: 100nF; Capacitor_0402; MPN CL05B104KB54PNC; LCSC C307331
C2: 100nF; Capacitor_0402; LCSC C307331
C6, C11: 4.7uF; Capacitor_0402; MPN CL05A475MP5NRNC; LCSC C23733
C8: 10nF; Capacitor_0402; MPN CL05B103KB5NNNC; LCSC C15195
C9: 1uF; Capacitor_0402; MPN CL05A105KA5NQNC; LCSC C52923
C12, C13: 1uF; Capacitor_0402; LCSC C52923
F1: Polyfuse; Fuse_Bourns_MF-RHT100
H1, H2, H3, H4: MountingHole; MountingHole_2.1mm
J1: USB_C; USB_C_HRO_TYPE-C-31-M-12; LCSC C165948
R5: 10k; Resistor_0402; LCSC C25744
R6, R7: 5.1k; Resistor_0402; LCSC C25905
SW343: SW_Push; Button_TL3342; LCSC C115351
U1: STM32F072CBT6; Package_LQFP-48_7x7mm_P0.5; LCSC C81720
U2: 74LVCH2T45DC; VSSOP-8_2.3x2mm_P0.5mm
U3: USBLC6-2SC6; ESD_SOT-23-6; LCSC C2827654
U4: XC6206; Voltage_SOT-23; LCSC C5446

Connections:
+3.3V: C1.2, C3.2, C6.2, C7.2, C8.2, C9.2, C10.2, C11.2, C13.1, SW343.1, U1.1 (VBAT), U1.9 (VDDA), U1.24 (VDD), U1.36 (VDDIO2), U1.48 (VDD), U2.5 (DIR), U2.8 (VCCB), U4.2 (VO)
/A10: U1.31 (PA10)
/A13: U1.34 (PA13)
/A14: U1.37 (PA14)
/A15: U1.38 (PA15)
/BOOT0: R5.2, SW343.2, U1.44 (BOOT0)
/C13: U1.2 (PC13)
/C14: U1.3 (PC14)
/C15: U1.4 (PC15)
/F0: U1.5 (PF0)
/F1: U1.6 (PF1)
/MCU_D+: U1.33 (PA12), U3.1 (I/O1)
/MCU_D-: U1.32 (PA11), U3.3 (I/O2)
/NRST: C2.1, U1.7 (NRST)
/USB_D+: J1.A6 (D+), J1.B6 (D+), U3.6 (I/O1)
/USB_D-: J1.A7 (D-), J1.B7 (D-), U3.4 (I/O2)
Col_0: U1.42 (PB6); also elsewhere on the board
Col_1: U1.43 (PB7); also elsewhere on the board
Col_2: U1.45 (PB8); also elsewhere on the board
Col_3: U1.46 (PB9); also elsewhere on the board
Col_4: U1.21 (PB10); also elsewhere on the board
Col_5: U1.22 (PB11); also elsewhere on the board
Col_6: U1.25 (PB12); also elsewhere on the board
Col_7: U1.26 (PB13); also elsewhere on the board
Col_8: U1.27 (PB14); also elsewhere on the board
Col_9: U1.28 (PB15); also elsewhere on the board
Col_10: U1.10 (PA0); also elsewhere on the board
Col_11: U1.11 (PA1); also elsewhere on the board
Col_12: U1.12 (PA2); also elsewhere on the board
Col_13: U1.14 (PA4); also elsewhere on the board
Col_14: U1.13 (PA3), U1.15 (PA5); also elsewhere on the board
Col_15: U1.16 (PA6); also elsewhere on the board
GND: C1.1, C2.2, C3.1, C6.1, C7.1, C8.1, C9.1, C10.1, C11.1, C12.2, C13.2, J1.A1 (GND), J1.A12 (GND), J1.B1 (GND), J1.B12 (GND), J1.S1 (SHIELD), R5.1, R6.2, R7.2, U1.8 (VSSA), U1.23 (VSS), U1.35 (VSS), U1.47 (VSS), U2.4 (GND), U3.2 (GND), U4.1 (GND); also elsewhere on the board
unnamed: J1.A5 (CC1), R6.1
unnamed: J1.B5 (CC2), R7.1
RGB_INPUT: U1.17 (PA7), U2.7 (1B)
RGB_OUTPUT: U2.2 (1A); also elsewhere on the board
Row_0: U1.18 (PB0); also elsewhere on the board
Row_1: U1.19 (PB1); also elsewhere on the board
Row_2: U1.20 (PB2); also elsewhere on the board
Row_3: U1.39 (PB3); also elsewhere on the board
Row_4: U1.40 (PB4); also elsewhere on the board
Row_5: U1.41 (PB5); also elsewhere on the board

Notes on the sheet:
Voltage Step Down
Other
USB-C
Keys
ESD Protection
STM32F072CBT6
Connector
Power Flags
Mounting Holes
Controller
Decoupling Capacitors
Power Converter
Matrix
LED Matrix
Bootloader Button
Hold when plugging in to enter bootloader mode.

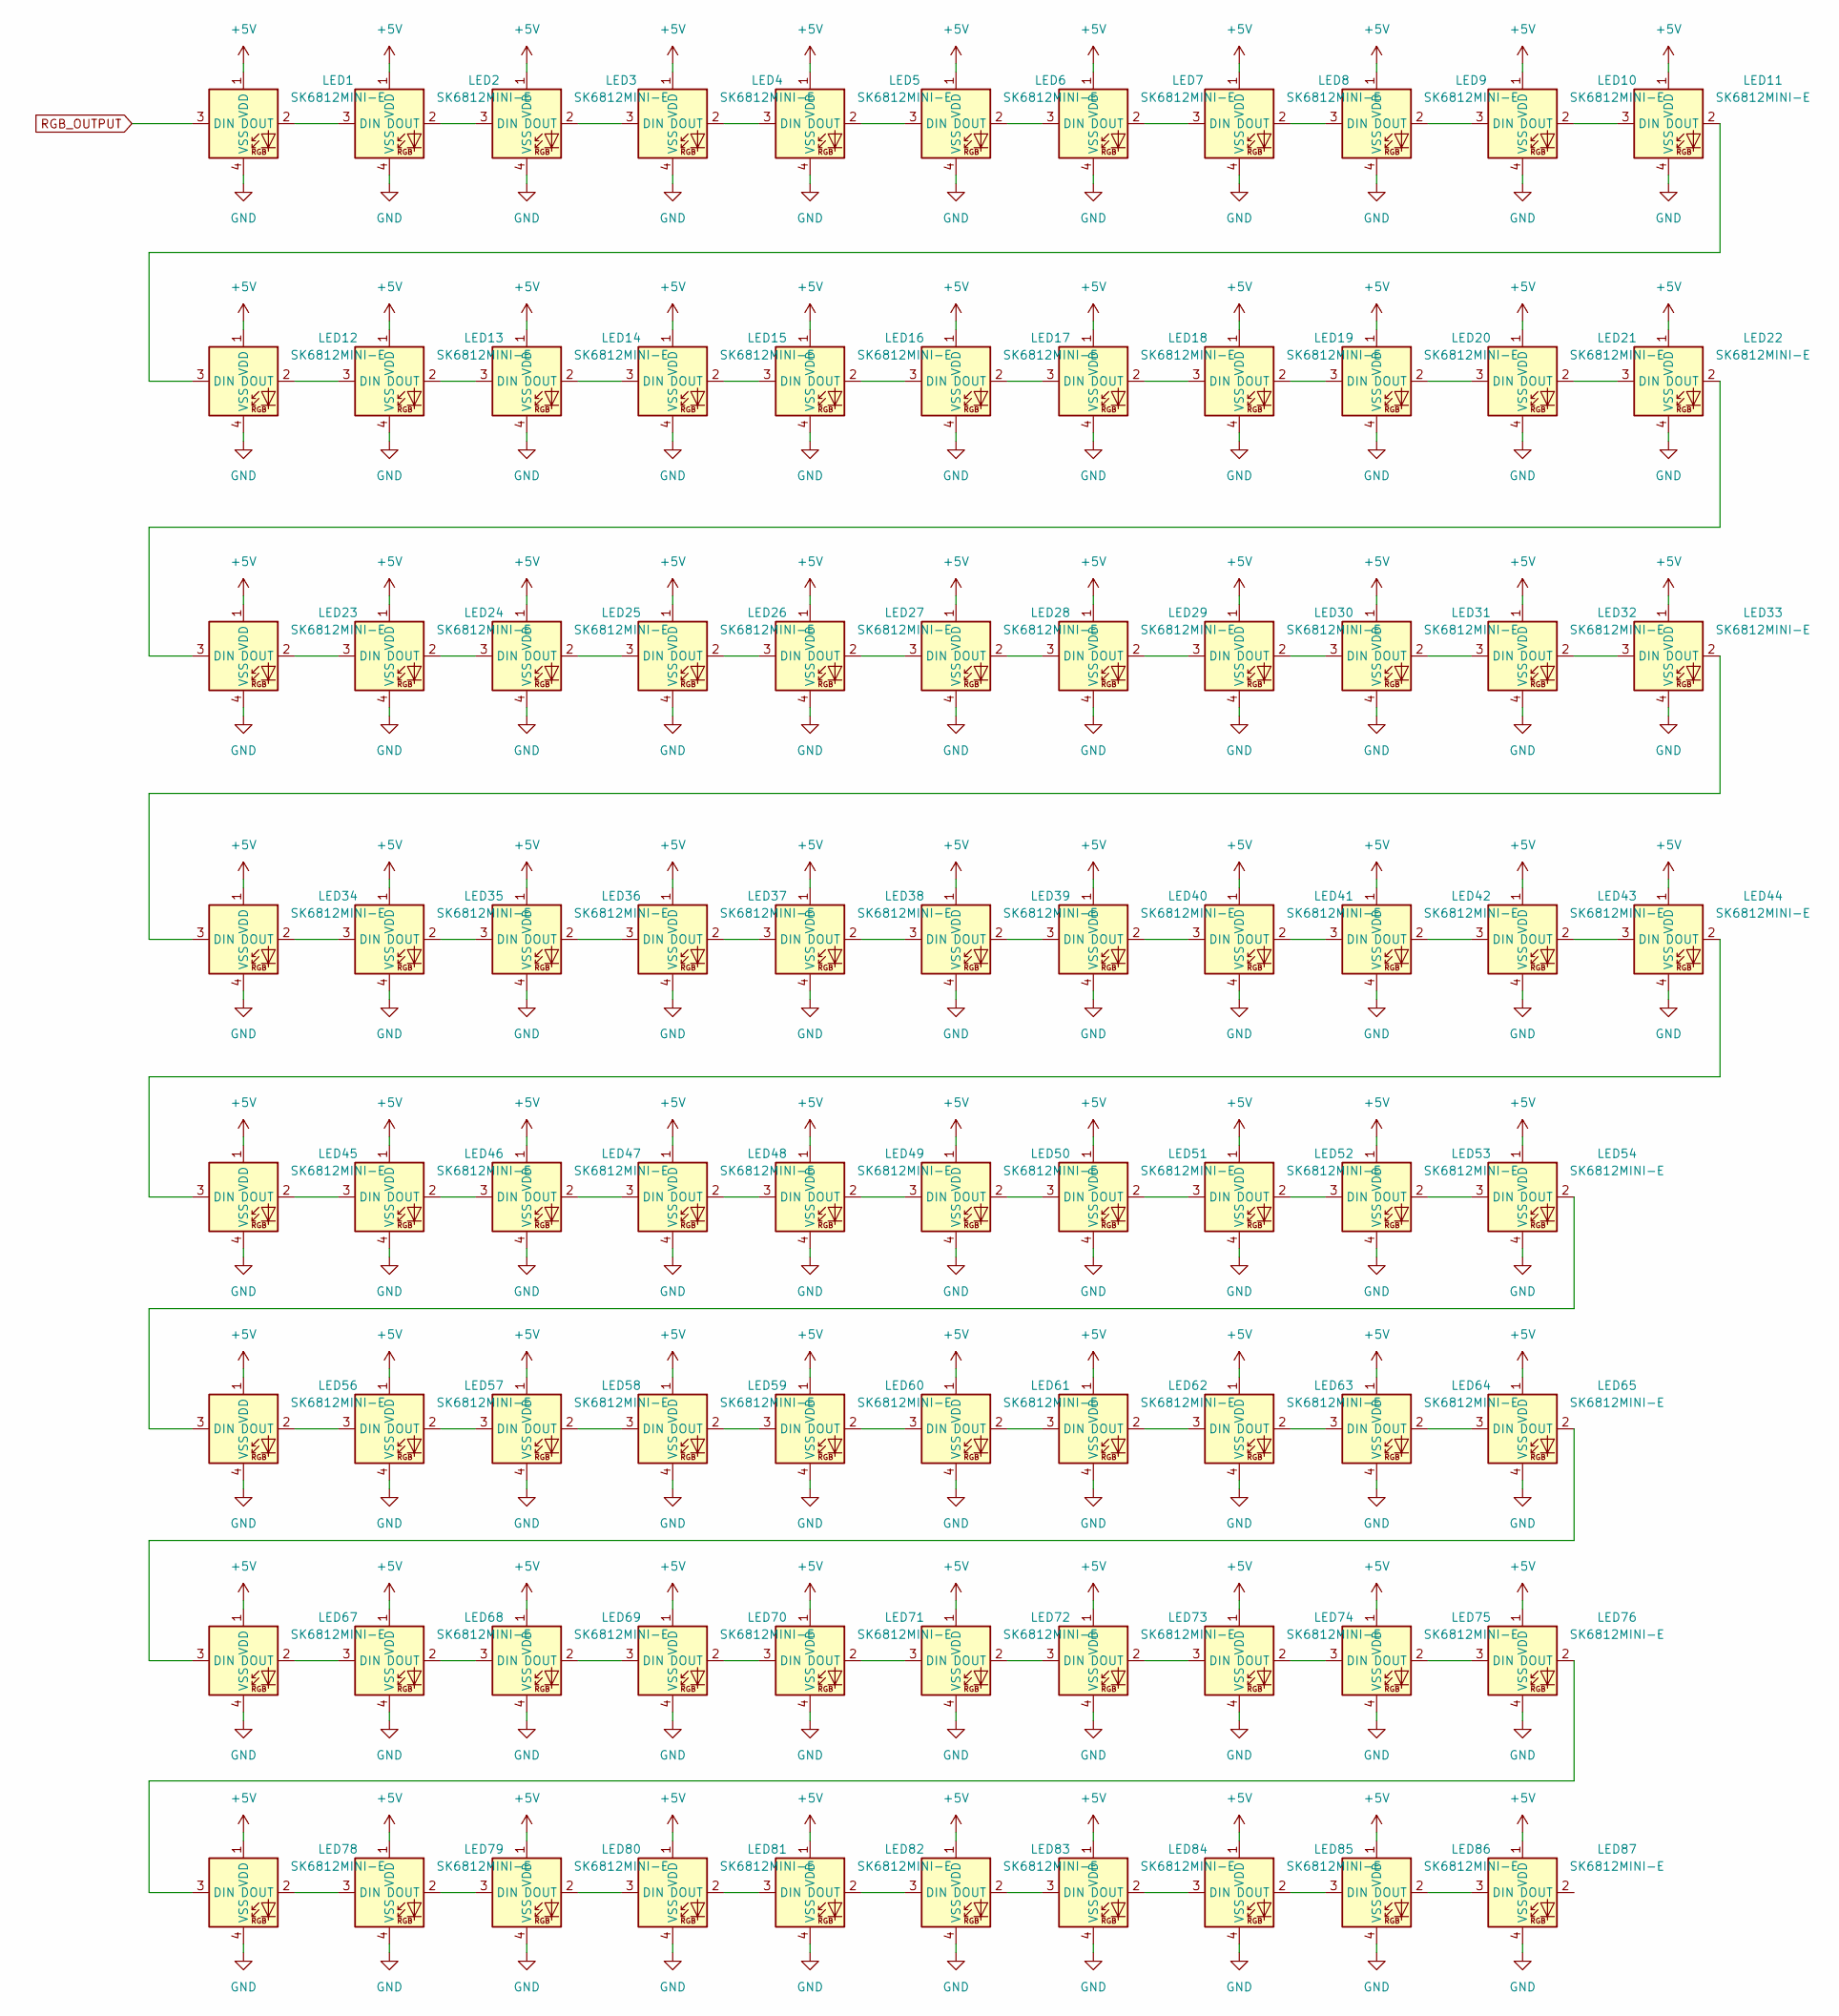
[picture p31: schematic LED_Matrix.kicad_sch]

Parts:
LED1, LED2, LED3, LED4, LED5, LED6, LED7, LED8, LED9, LED10, LED11, LED12, LED13, LED14, LED15, LED16, LED17, LED18, LED19, LED20, LED21, LED22, LED23, LED24, LED25, LED26, LED27, LED28, LED29, LED30, LED31, LED32, LED33, LED34, LED35, LED36, LED37, LED38, LED39, LED40, LED41, LED42, LED43, LED44, LED45, LED46, LED47, LED48, LED49, LED50, LED51, LED52, LED53, LED54, LED56, LED57, LED58, LED59, LED60, LED61, LED62, LED63, LED64, LED65, LED67, LED68, LED69, LED70, LED71, LED72, LED73, LED74, LED75, LED76, LED78, LED79, LED80, LED81, LED82, LED83, LED84, LED85, LED86, LED87: SK6812MINI-E; LED_6028R

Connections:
GND: LED1.4 (VSS), LED2.4 (VSS), LED3.4 (VSS), LED4.4 (VSS), LED5.4 (VSS), LED6.4 (VSS), LED7.4 (VSS), LED8.4 (VSS), LED9.4 (VSS), LED10.4 (VSS), LED11.4 (VSS), LED12.4 (VSS), LED13.4 (VSS), LED14.4 (VSS), LED15.4 (VSS), LED16.4 (VSS), LED17.4 (VSS), LED18.4 (VSS), LED19.4 (VSS), LED20.4 (VSS), LED21.4 (VSS), LED22.4 (VSS), LED23.4 (VSS), LED24.4 (VSS), LED25.4 (VSS), LED26.4 (VSS), LED27.4 (VSS), LED28.4 (VSS), LED29.4 (VSS), LED30.4 (VSS), LED31.4 (VSS), LED32.4 (VSS), LED33.4 (VSS), LED34.4 (VSS), LED35.4 (VSS), LED36.4 (VSS), LED37.4 (VSS), LED38.4 (VSS), LED39.4 (VSS), LED40.4 (VSS), LED41.4 (VSS), LED42.4 (VSS), LED43.4 (VSS), LED44.4 (VSS), LED45.4 (VSS), LED46.4 (VSS), LED47.4 (VSS), LED48.4 (VSS), LED49.4 (VSS), LED50.4 (VSS), LED51.4 (VSS), LED52.4 (VSS), LED53.4 (VSS), LED54.4 (VSS), LED56.4 (VSS), LED57.4 (VSS), LED58.4 (VSS), LED59.4 (VSS), LED60.4 (VSS), LED61.4 (VSS), LED62.4 (VSS), LED63.4 (VSS), LED64.4 (VSS), LED65.4 (VSS), LED67.4 (VSS), LED68.4 (VSS), LED69.4 (VSS), LED70.4 (VSS), LED71.4 (VSS), LED72.4 (VSS), LED73.4 (VSS), LED74.4 (VSS), LED75.4 (VSS), LED76.4 (VSS), LED78.4 (VSS), LED79.4 (VSS), LED80.4 (VSS), LED81.4 (VSS), LED82.4 (VSS), LED83.4 (VSS), LED84.4 (VSS), LED85.4 (VSS), LED86.4 (VSS), LED87.4 (VSS); also elsewhere on the board
unnamed: LED1.2 (DOUT), LED2.3 (DIN)
unnamed: LED2.2 (DOUT), LED3.3 (DIN)
unnamed: LED3.2 (DOUT), LED4.3 (DIN)
unnamed: LED4.2 (DOUT), LED5.3 (DIN)
unnamed: LED5.2 (DOUT), LED6.3 (DIN)
unnamed: LED6.2 (DOUT), LED7.3 (DIN)
unnamed: LED7.2 (DOUT), LED8.3 (DIN)
unnamed: LED8.2 (DOUT), LED9.3 (DIN)
unnamed: LED9.2 (DOUT), LED10.3 (DIN)
unnamed: LED10.2 (DOUT), LED11.3 (DIN)
unnamed: LED11.2 (DOUT), LED12.3 (DIN)
unnamed: LED12.2 (DOUT), LED13.3 (DIN)
unnamed: LED13.2 (DOUT), LED14.3 (DIN)
unnamed: LED14.2 (DOUT), LED15.3 (DIN)
unnamed: LED15.2 (DOUT), LED16.3 (DIN)
unnamed: LED16.2 (DOUT), LED17.3 (DIN)
unnamed: LED17.2 (DOUT), LED18.3 (DIN)
unnamed: LED18.2 (DOUT), LED19.3 (DIN)
unnamed: LED19.2 (DOUT), LED20.3 (DIN)
unnamed: LED20.2 (DOUT), LED21.3 (DIN)
unnamed: LED21.2 (DOUT), LED22.3 (DIN)
unnamed: LED22.2 (DOUT), LED23.3 (DIN)
unnamed: LED23.2 (DOUT), LED24.3 (DIN)
unnamed: LED24.2 (DOUT), LED25.3 (DIN)
unnamed: LED25.2 (DOUT), LED26.3 (DIN)
unnamed: LED26.2 (DOUT), LED27.3 (DIN)
unnamed: LED27.2 (DOUT), LED28.3 (DIN)
unnamed: LED28.2 (DOUT), LED29.3 (DIN)
unnamed: LED29.2 (DOUT), LED30.3 (DIN)
unnamed: LED30.2 (DOUT), LED31.3 (DIN)
unnamed: LED31.2 (DOUT), LED32.3 (DIN)
unnamed: LED32.2 (DOUT), LED33.3 (DIN)
unnamed: LED33.2 (DOUT), LED34.3 (DIN)
unnamed: LED34.2 (DOUT), LED35.3 (DIN)
unnamed: LED35.2 (DOUT), LED36.3 (DIN)
unnamed: LED36.2 (DOUT), LED37.3 (DIN)
unnamed: LED37.2 (DOUT), LED38.3 (DIN)
unnamed: LED38.2 (DOUT), LED39.3 (DIN)
unnamed: LED39.2 (DOUT), LED40.3 (DIN)
unnamed: LED40.2 (DOUT), LED41.3 (DIN)
unnamed: LED41.2 (DOUT), LED42.3 (DIN)
unnamed: LED42.2 (DOUT), LED43.3 (DIN)
unnamed: LED43.2 (DOUT), LED44.3 (DIN)
unnamed: LED44.2 (DOUT), LED45.3 (DIN)
unnamed: LED45.2 (DOUT), LED46.3 (DIN)
unnamed: LED46.2 (DOUT), LED47.3 (DIN)
unnamed: LED47.2 (DOUT), LED48.3 (DIN)
unnamed: LED48.2 (DOUT), LED49.3 (DIN)
unnamed: LED49.2 (DOUT), LED50.3 (DIN)
unnamed: LED50.2 (DOUT), LED51.3 (DIN)
unnamed: LED51.2 (DOUT), LED52.3 (DIN)
unnamed: LED52.2 (DOUT), LED53.3 (DIN)
unnamed: LED53.2 (DOUT), LED54.3 (DIN)
unnamed: LED54.2 (DOUT), LED56.3 (DIN)
unnamed: LED56.2 (DOUT), LED57.3 (DIN)
unnamed: LED57.2 (DOUT), LED58.3 (DIN)
unnamed: LED58.2 (DOUT), LED59.3 (DIN)
unnamed: LED59.2 (DOUT), LED60.3 (DIN)
unnamed: LED60.2 (DOUT), LED61.3 (DIN)
unnamed: LED61.2 (DOUT), LED62.3 (DIN)
unnamed: LED62.2 (DOUT), LED63.3 (DIN)
unnamed: LED63.2 (DOUT), LED64.3 (DIN)
unnamed: LED64.2 (DOUT), LED65.3 (DIN)
unnamed: LED65.2 (DOUT), LED67.3 (DIN)
unnamed: LED67.2 (DOUT), LED68.3 (DIN)
unnamed: LED68.2 (DOUT), LED69.3 (DIN)
unnamed: LED69.2 (DOUT), LED70.3 (DIN)
unnamed: LED70.2 (DOUT), LED71.3 (DIN)
unnamed: LED71.2 (DOUT), LED72.3 (DIN)
unnamed: LED72.2 (DOUT), LED73.3 (DIN)
unnamed: LED73.2 (DOUT), LED74.3 (DIN)
unnamed: LED74.2 (DOUT), LED75.3 (DIN)
unnamed: LED75.2 (DOUT), LED76.3 (DIN)
unnamed: LED76.2 (DOUT), LED78.3 (DIN)
unnamed: LED78.2 (DOUT), LED79.3 (DIN)
unnamed: LED79.2 (DOUT), LED80.3 (DIN)
unnamed: LED80.2 (DOUT), LED81.3 (DIN)
unnamed: LED81.2 (DOUT), LED82.3 (DIN)
unnamed: LED82.2 (DOUT), LED83.3 (DIN)
unnamed: LED83.2 (DOUT), LED84.3 (DIN)
unnamed: LED84.2 (DOUT), LED85.3 (DIN)
unnamed: LED85.2 (DOUT), LED86.3 (DIN)
unnamed: LED86.2 (DOUT), LED87.3 (DIN)
RGB_OUTPUT: LED1.3 (DIN); also elsewhere on the board

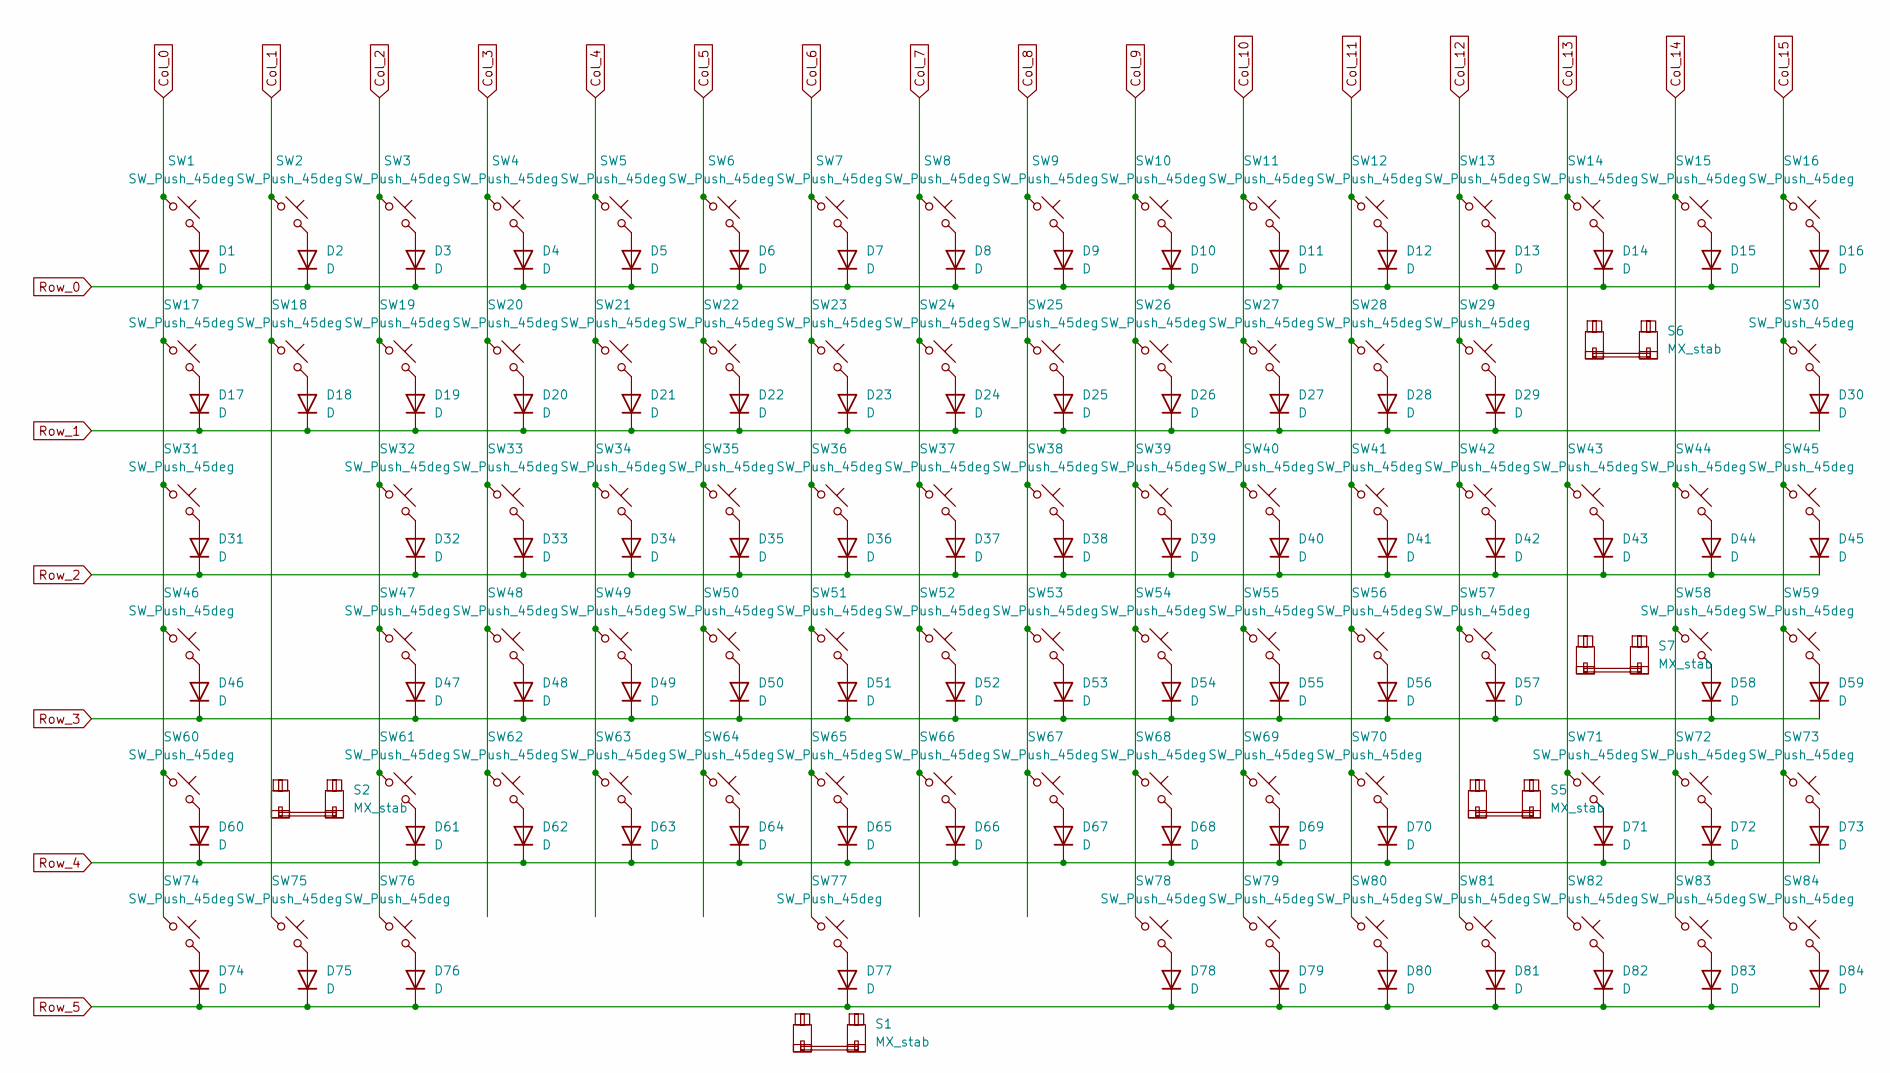
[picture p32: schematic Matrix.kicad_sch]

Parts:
D1, D2, D3, D4, D5, D6, D7, D8, D9, D10, D11, D12, D13, D14, D15, D16, D17, D18, D19, D20, D21, D22, D23, D24, D25, D26, D27, D28, D29, D30, D31, D32, D33, D34, D35, D36, D37, D38, D39, D40, D41, D42, D43, D44, D45, D46, D47, D48, D49, D50, D51, D52, D53, D54, D55, D56, D57, D58, D59, D60, D61, D62, D63, D64, D65, D66, D67, D68, D69, D70, D71, D72, D73, D74, D75, D76, D77, D78, D79, D80, D81, D82, D83, D84: D; D_0201_0603Metric
S1: MX_stab; STAB_MX_P_6.25u
S2: MX_stab; STAB_MX_P_2.25u
S5: MX_stab; STAB_MX_2u
S6: MX_stab; STAB_MX_P_2u
S7: MX_stab; STAB_MX_2.25u
SW1, SW2, SW3, SW4, SW5, SW6, SW7, SW8, SW9, SW10, SW11, SW12, SW13, SW14, SW15, SW16, SW17, SW18, SW19, SW20, SW21, SW22, SW23, SW24, SW25, SW26, SW27, SW28, SW29, SW30, SW31, SW32, SW33, SW34, SW35, SW36, SW37, SW38, SW39, SW40, SW41, SW42, SW43, SW44, SW45, SW46, SW47, SW48, SW49, SW50, SW51, SW52, SW53, SW54, SW55, SW56, SW57, SW58, SW59, SW60, SW61, SW62, SW63, SW64, SW65, SW66, SW67, SW68, SW69, SW70, SW71, SW72, SW73, SW74, SW75, SW76, SW77, SW78, SW79, SW80, SW81, SW82, SW83, SW84: SW_Push_45deg; SW_Cherry_MX_PCB_1.00u

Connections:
Col_0: SW1.1, SW17.1, SW31.1, SW46.1, SW60.1, SW74.1; also elsewhere on the board
Col_1: SW2.1, SW18.1, SW75.1; also elsewhere on the board
Col_2: SW3.1, SW19.1, SW32.1, SW47.1, SW61.1, SW76.1; also elsewhere on the board
Col_3: SW4.1, SW20.1, SW33.1, SW48.1, SW62.1; also elsewhere on the board
Col_4: SW5.1, SW21.1, SW34.1, SW49.1, SW63.1; also elsewhere on the board
Col_5: SW6.1, SW22.1, SW35.1, SW50.1, SW64.1; also elsewhere on the board
Col_6: SW7.1, SW23.1, SW36.1, SW51.1, SW65.1, SW77.1; also elsewhere on the board
Col_7: SW8.1, SW24.1, SW37.1, SW52.1, SW66.1; also elsewhere on the board
Col_8: SW9.1, SW25.1, SW38.1, SW53.1, SW67.1; also elsewhere on the board
Col_9: SW10.1, SW26.1, SW39.1, SW54.1, SW68.1, SW78.1; also elsewhere on the board
Col_10: SW11.1, SW27.1, SW40.1, SW55.1, SW69.1, SW79.1; also elsewhere on the board
Col_11: SW12.1, SW28.1, SW41.1, SW56.1, SW70.1, SW80.1; also elsewhere on the board
Col_12: SW13.1, SW29.1, SW42.1, SW57.1, SW81.1; also elsewhere on the board
Col_13: SW14.1, SW43.1, SW71.1, SW82.1; also elsewhere on the board
Col_14: SW15.1, SW44.1, SW58.1, SW72.1, SW83.1; also elsewhere on the board
Col_15: SW16.1, SW30.1, SW45.1, SW59.1, SW73.1, SW84.1; also elsewhere on the board
unnamed: D1.2 (A), SW1.2
unnamed: D2.2 (A), SW2.2
unnamed: D3.2 (A), SW3.2
unnamed: D4.2 (A), SW4.2
unnamed: D5.2 (A), SW5.2
unnamed: D6.2 (A), SW6.2
unnamed: D7.2 (A), SW7.2
unnamed: D8.2 (A), SW8.2
unnamed: D9.2 (A), SW9.2
unnamed: D10.2 (A), SW10.2
unnamed: D11.2 (A), SW11.2
unnamed: D12.2 (A), SW12.2
unnamed: D13.2 (A), SW13.2
unnamed: D14.2 (A), SW14.2
unnamed: D15.2 (A), SW15.2
unnamed: D16.2 (A), SW16.2
unnamed: D17.2 (A), SW17.2
unnamed: D18.2 (A), SW18.2
unnamed: D19.2 (A), SW19.2
unnamed: D20.2 (A), SW20.2
unnamed: D21.2 (A), SW21.2
unnamed: D22.2 (A), SW22.2
unnamed: D23.2 (A), SW23.2
unnamed: D24.2 (A), SW24.2
unnamed: D25.2 (A), SW25.2
unnamed: D26.2 (A), SW26.2
unnamed: D27.2 (A), SW27.2
unnamed: D28.2 (A), SW28.2
unnamed: D29.2 (A), SW29.2
unnamed: D30.2 (A), SW30.2
unnamed: D31.2 (A), SW31.2
unnamed: D32.2 (A), SW32.2
unnamed: D33.2 (A), SW33.2
unnamed: D34.2 (A), SW34.2
unnamed: D35.2 (A), SW35.2
unnamed: D36.2 (A), SW36.2
unnamed: D37.2 (A), SW37.2
unnamed: D38.2 (A), SW38.2
unnamed: D39.2 (A), SW39.2
unnamed: D40.2 (A), SW40.2
unnamed: D41.2 (A), SW41.2
unnamed: D42.2 (A), SW42.2
unnamed: D43.2 (A), SW43.2
unnamed: D44.2 (A), SW44.2
unnamed: D45.2 (A), SW45.2
unnamed: D46.2 (A), SW46.2
unnamed: D47.2 (A), SW47.2
unnamed: D48.2 (A), SW48.2
unnamed: D49.2 (A), SW49.2
unnamed: D50.2 (A), SW50.2
unnamed: D51.2 (A), SW51.2
unnamed: D52.2 (A), SW52.2
unnamed: D53.2 (A), SW53.2
unnamed: D54.2 (A), SW54.2
unnamed: D55.2 (A), SW55.2
unnamed: D56.2 (A), SW56.2
unnamed: D57.2 (A), SW57.2
unnamed: D58.2 (A), SW58.2
unnamed: D59.2 (A), SW59.2
unnamed: D60.2 (A), SW60.2
unnamed: D61.2 (A), SW61.2
unnamed: D62.2 (A), SW62.2
unnamed: D63.2 (A), SW63.2
unnamed: D64.2 (A), SW64.2
unnamed: D65.2 (A), SW65.2
unnamed: D66.2 (A), SW66.2
unnamed: D67.2 (A), SW67.2
unnamed: D68.2 (A), SW68.2
unnamed: D69.2 (A), SW69.2
unnamed: D70.2 (A), SW70.2
unnamed: D71.2 (A), SW71.2
unnamed: D72.2 (A), SW72.2
unnamed: D73.2 (A), SW73.2
unnamed: D74.2 (A), SW74.2
unnamed: D75.2 (A), SW75.2
unnamed: D76.2 (A), SW76.2
unnamed: D77.2 (A), SW77.2
unnamed: D78.2 (A), SW78.2
unnamed: D79.2 (A), SW79.2
unnamed: D80.2 (A), SW80.2
unnamed: D81.2 (A), SW81.2
unnamed: D82.2 (A), SW82.2
unnamed: D83.2 (A), SW83.2
unnamed: D84.2 (A), SW84.2
Row_0: D1.1 (K), D2.1 (K), D3.1 (K), D4.1 (K), D5.1 (K), D6.1 (K), D7.1 (K), D8.1 (K), D9.1 (K), D10.1 (K), D11.1 (K), D12.1 (K), D13.1 (K), D14.1 (K), D15.1 (K), D16.1 (K); also elsewhere on the board
Row_1: D17.1 (K), D18.1 (K), D19.1 (K), D20.1 (K), D21.1 (K), D22.1 (K), D23.1 (K), D24.1 (K), D25.1 (K), D26.1 (K), D27.1 (K), D28.1 (K), D29.1 (K), D30.1 (K); also elsewhere on the board
Row_2: D31.1 (K), D32.1 (K), D33.1 (K), D34.1 (K), D35.1 (K), D36.1 (K), D37.1 (K), D38.1 (K), D39.1 (K), D40.1 (K), D41.1 (K), D42.1 (K), D43.1 (K), D44.1 (K), D45.1 (K); also elsewhere on the board
Row_3: D46.1 (K), D47.1 (K), D48.1 (K), D49.1 (K), D50.1 (K), D51.1 (K), D52.1 (K), D53.1 (K), D54.1 (K), D55.1 (K), D56.1 (K), D57.1 (K), D58.1 (K), D59.1 (K); also elsewhere on the board
Row_4: D60.1 (K), D61.1 (K), D62.1 (K), D63.1 (K), D64.1 (K), D65.1 (K), D66.1 (K), D67.1 (K), D68.1 (K), D69.1 (K), D70.1 (K), D71.1 (K), D72.1 (K), D73.1 (K); also elsewhere on the board
Row_5: D74.1 (K), D75.1 (K), D76.1 (K), D77.1 (K), D78.1 (K), D79.1 (K), D80.1 (K), D81.1 (K), D82.1 (K), D83.1 (K), D84.1 (K); also elsewhere on the board

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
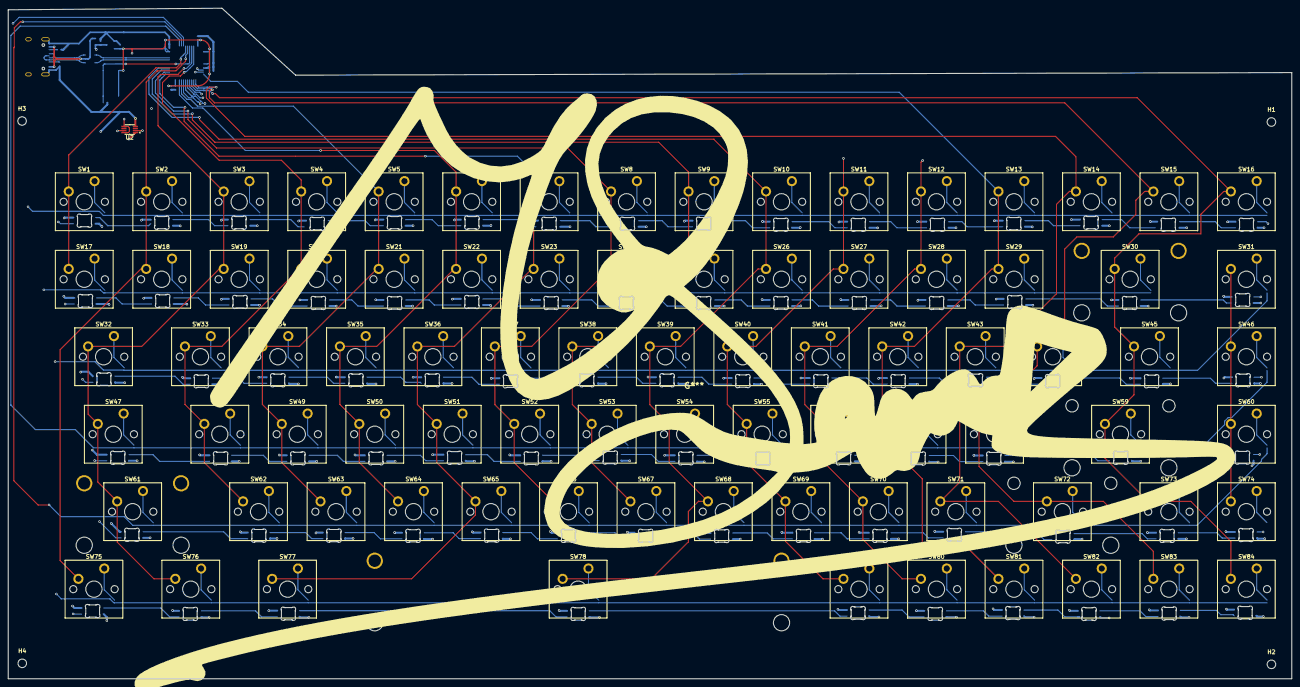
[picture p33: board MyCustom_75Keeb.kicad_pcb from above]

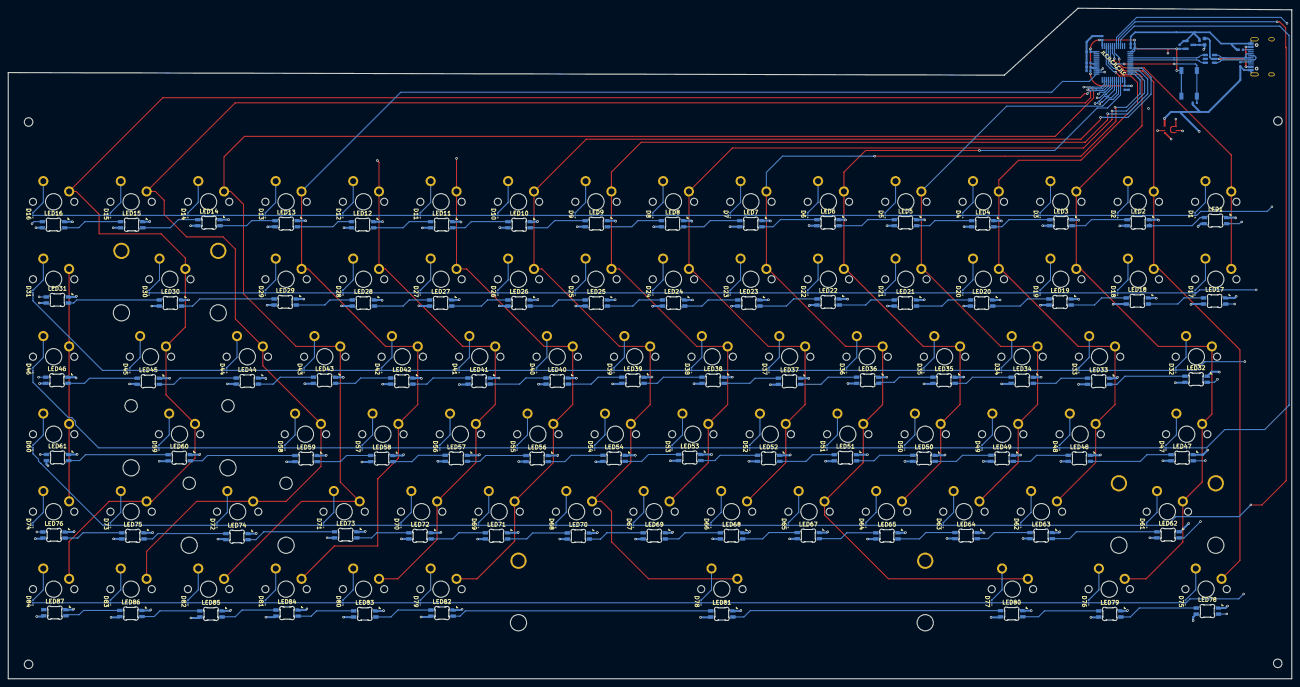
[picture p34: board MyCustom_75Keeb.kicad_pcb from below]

Board: 4 copper layers, 315.6 x 164.9 mm, 282 parts (188 on the bottom side), 203 nets.

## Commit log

2025-12-04 all files
    [LED_Matrix.kicad_sch, Matrix.kicad_sch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]
2025-12-04 all files after edit
    [MyCustom_75Keeb.csv, MyCustom_75Keeb.xlsx]
2025-12-04 Readme correction
    [MyCustom_75Keeb.csv]
2025-12-07 BOM fix
    [BOM.csv]
2026-01-06 Update BOM.csv to reflect new total labels
    [BOM.csv]
2026-01-16 PCB CASE step files
    [PCB_CASE_BOTTOM.step, PCB_Case_UPPER.step]
2026-01-16 PCB Case Design Images
2026-01-16 Document keyboard case design and end result
    Added details about the keyboard case design and images.
